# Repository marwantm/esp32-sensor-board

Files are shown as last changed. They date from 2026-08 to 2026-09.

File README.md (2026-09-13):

# ESP32 Sensor Board

A 4-layer ESP32-C3 IoT sensor board with onboard LiPo charging, SD storage, and a multi-sensor front end, designed in KiCad by following Tech Explorations' full board-development pipeline tutorial — my most advanced build yet, covering the complete flow from schematic to manufacturing and assembly.

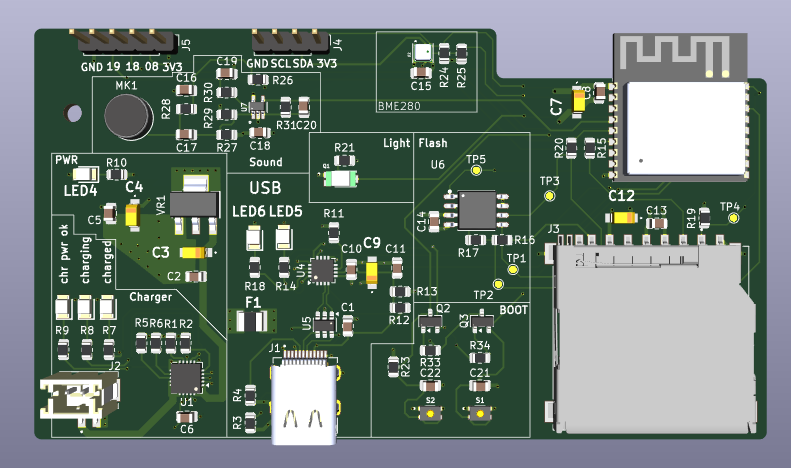
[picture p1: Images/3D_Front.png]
PCB 3D Front


## Overview

This board is built around the **ESP32-C3-WROOM-02**, a RISC-V Wi-Fi/BLE module, paired with a small sensor suite (environmental, audio, and light), onboard SPI flash, microSD storage, and a full LiPo battery charging path — a compact, self-contained IoT sensor node platform.

| | |
|---|---|
| **MCU** | ESP32-C3-WROOM-02 (RISC-V, Wi-Fi + BLE) |
| **Sensors** | BME280 (temperature/humidity/pressure), electret mic + MAX4466 amplifier, TEMT6000 ambient light sensor |
| **Storage** | W25Q32JVSSIQ SPI flash (32 Mbit) + microSD card slot |
| **Connectivity** | USB-C (via CP2102N USB-UART bridge), I2C header for OLED display, GPIO breakout |
| **Power** | USB-C (5V) or LiPo battery (JST connector), MCP73871 Li-ion/LiPo charge management, LM1117MPX-3.3 LDO |
| **Programming** | Auto-program circuit (DTR/RTS → EN/IO0 via BC817 transistors) — no manual boot/reset sequence needed |
| **PCB** | 4-layer |
| **Design Tool** | KiCad 9 |

## What I Learned

This project pushed further than my previous boards, moving from single-sheet schematics and simple 2-layer boards into a full multilayer design with manufacturing and assembly considerations built in from the start:

**Schematic Design**
- Multi-sheet hierarchical schematic structure, splitting the design into logical sub-sheets (USB/flash, sensors, user interface, power)
- Creating a custom KiCad component library for parts not available in the standard libraries, registered globally for reuse in future projects
- Designing a complete LiPo charging path around the MCP73871, including charge-status indication (charging/charged LEDs) and battery sense/thermistor handling

**PCB Layout**
- Working with a 4-layer stack-up and signal tuning across layers
- Zone fills across both available and non-available power planes, and understanding how that affects plane continuity and return paths
- Component placement and routing for mixed digital, analog (microphone/amp), and RF (Wi-Fi/BLE) sections on the same board

**Manufacturing & Assembly**
- Design for Manufacturability (DFM) checks using HQDFM (NextPCB)
- Generating centroid (pick-and-place) files for PCB assembly
- Thinking through the board as something meant to be assembled by a fab, not just etched and hand-soldered

## Gallery

| Schematic (Power & USB) | Schematic (ESP32, USB, Flash) |
|---|---|
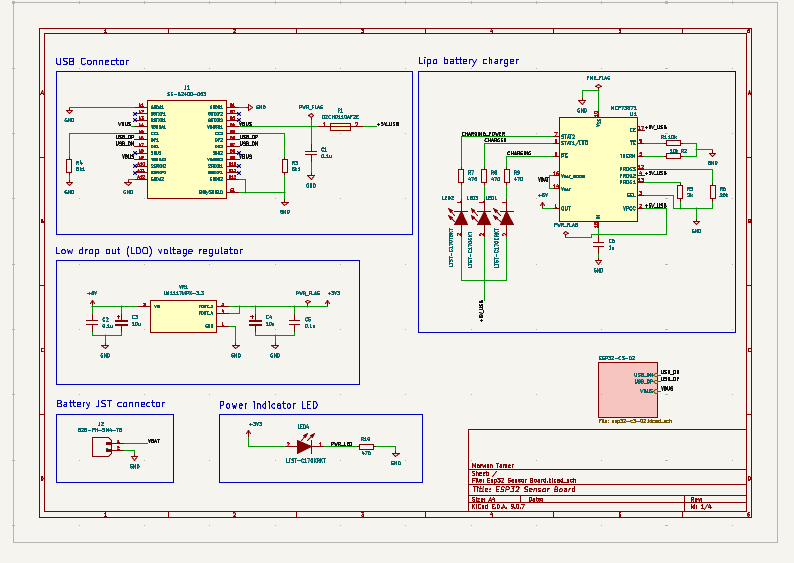
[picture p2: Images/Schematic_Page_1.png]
Schematic Page 1
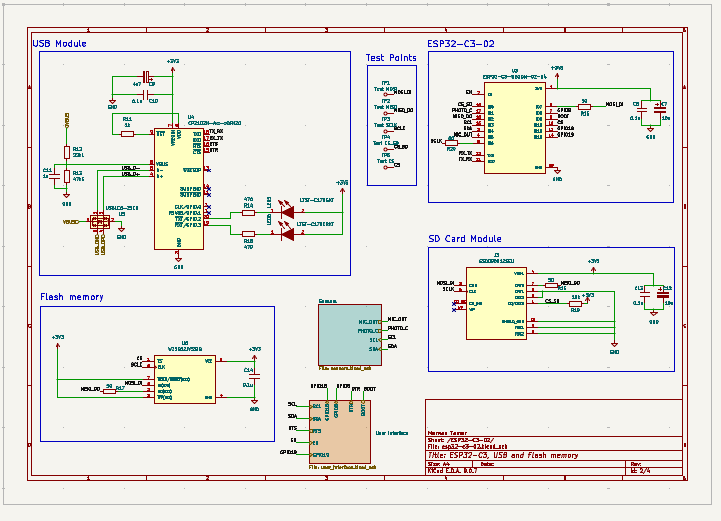
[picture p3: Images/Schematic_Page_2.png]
Schematic Page 2
|  |  |

| Schematic (Sensors) | Schematic (User Interface) |
|---|---|
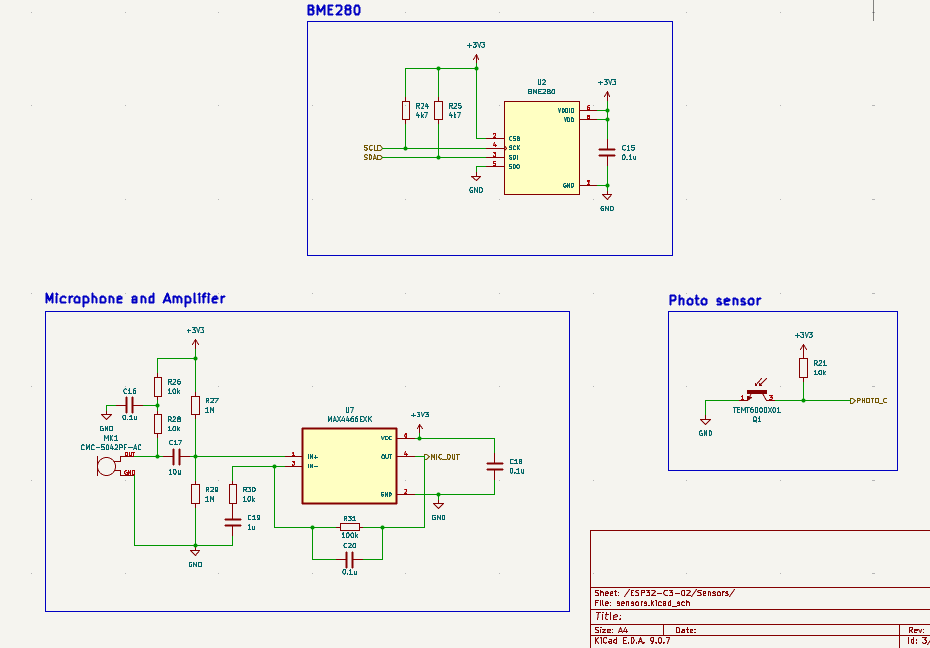
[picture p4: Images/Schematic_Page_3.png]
Schematic Page 3
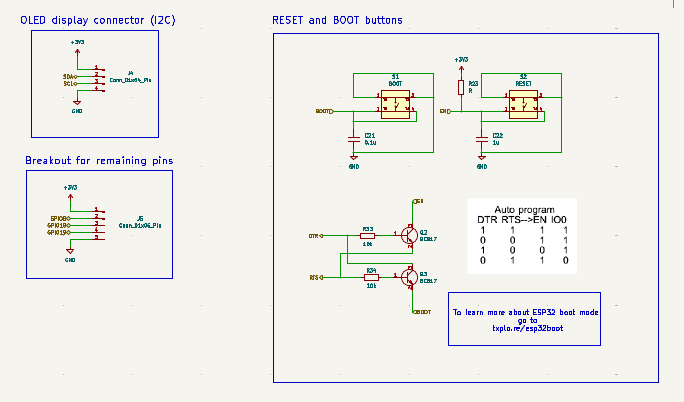
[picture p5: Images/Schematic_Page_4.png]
Schematic Page 4
|  |  |

| PCB Top | PCB Bottom |
|---|---|
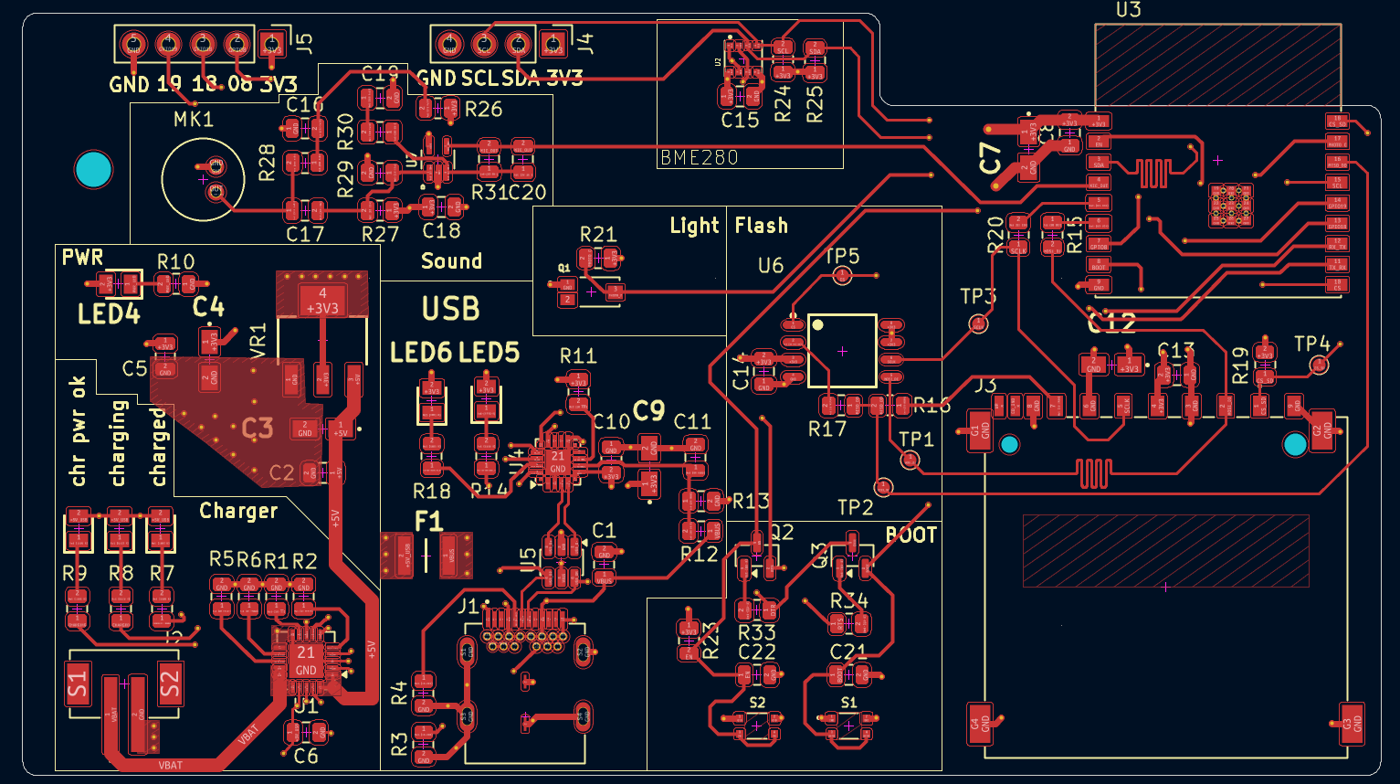
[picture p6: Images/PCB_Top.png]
PCB Top
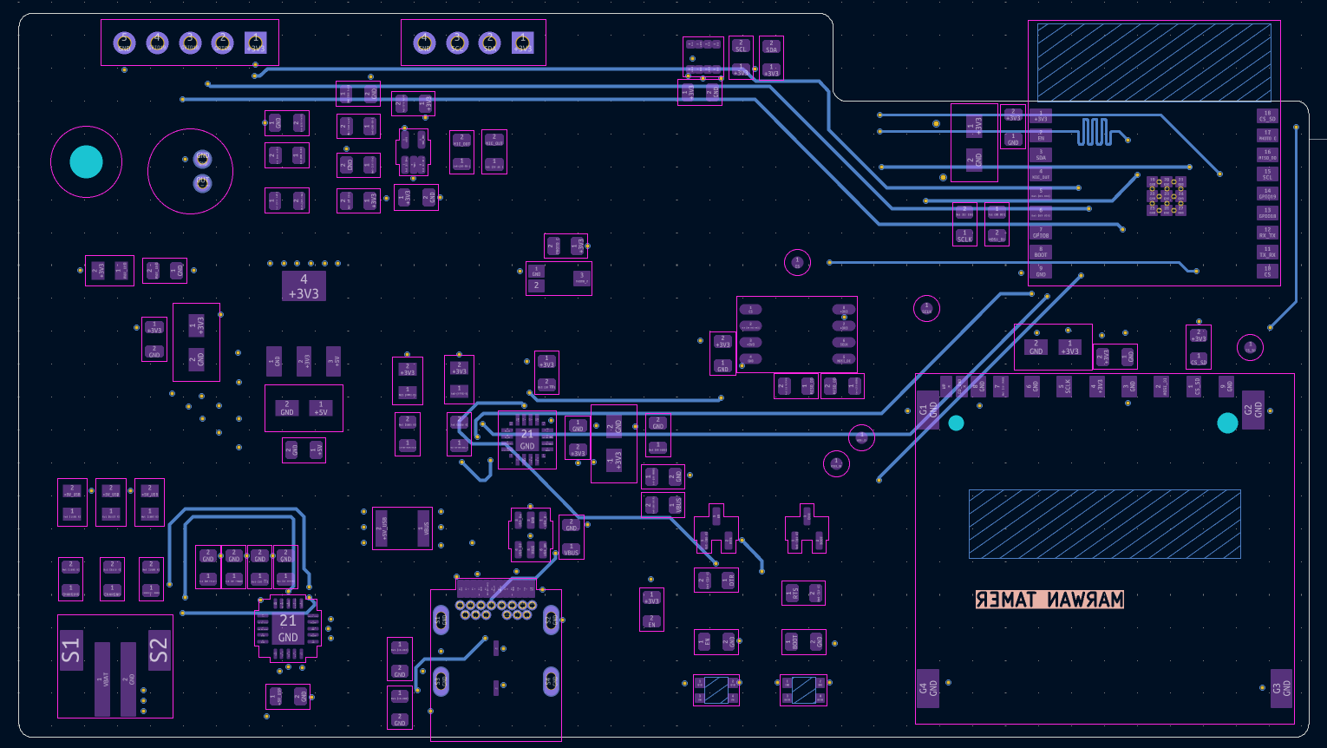
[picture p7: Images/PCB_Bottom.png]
PCB Bottom
|  |  |

| 3D Front | 3D Back |
|---|---|
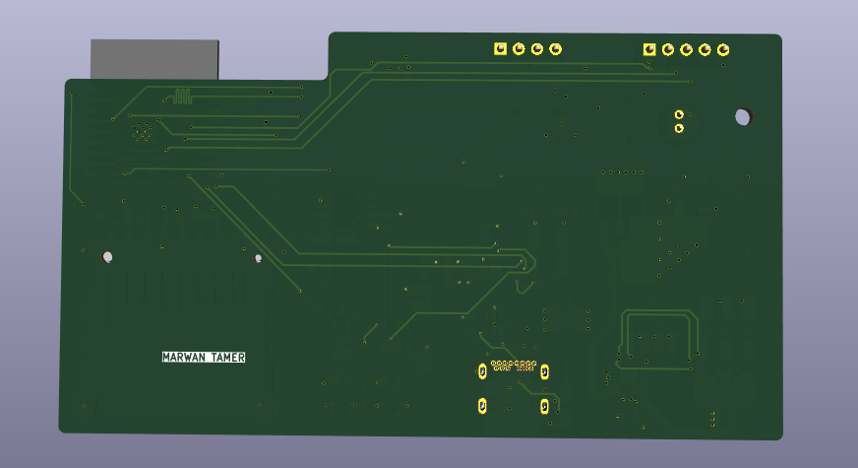
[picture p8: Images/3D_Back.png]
3D Back
| 3D Front |  |

## Repository Structure

```
ESP32-Sensor-Board/
├── README.md
├── Hardware/                        # Manufacturing-ready outputs
│   ├── ESP32 Sensor Board_Schematic.pdf
│   ├── ESP32 Sensor Board_PCB.pdf
│   ├── BOM.csv
│   └── Gerbers.zip
├── Images/                          # Renders and layer screenshots
│   ├── 3D_Back.png
│   ├── 3D_Front.png
│   ├── PCB_Bottom.png
│   ├── PCB_Top.png
│   ├── Schematic_Page_1.png
│   ├── Schematic_Page_2.png
│   ├── Schematic_Page_3.png
│   └── Schematic_Page_4.png
└── Source Files/                    # Full KiCad project (editable source)
    ├── Additional Components/       # Custom library (parts, footprints)
    ├── Esp32 Sensor Board.kicad_pcb
    ├── Esp32 Sensor Board.kicad_prl
    ├── Esp32 Sensor Board.kicad_pro
    ├── Esp32 Sensor Board.kicad_sch
    ├── esp32-c3-02.kicad_sch
    ├── sensors.kicad_sch
    ├── user_interface.kicad_sch
    └── fp-lib-table
```

## Credit

Built by following [Tech Explorations](https://www.linkedin.com/company/techexplorations/)'s ESP32 sensor board tutorial, which covers the complete pipeline from board specification through ordering and assembly. This project is a learning exercise, not an original design — full credit for the schematic architecture and design decisions goes to Tech Explorations' tutorial series.

## Author

**Marwan Tamer**
Electrical Power Engineering student, building toward Embedded Systems Engineering
[LinkedIn](https://www.linkedin.com/in/-marwan-tamer)

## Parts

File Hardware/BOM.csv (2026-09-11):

Reference | Qty | Value | DNP | Exclude from BOM | Exclude from Board | Footprint | Datasheet
C1,C2,C5,C8,C10,C13,C14,C15,C16,C18,C20,C21 | 12 | 0.1u |  |  |  | Capacitor_SMD:C_0805_2012Metric | ~
C3,C4,C7,C12 | 4 | 10u |  |  |  | My_Library:T491A | ~
C6,C11,C19,C22 | 4 | 1u |  |  |  | Capacitor_SMD:C_0805_2012Metric | ~
C9 | 1 | 4u7 |  |  |  | My_Library:T491A | ~
C17 | 1 | 10u |  |  |  | Capacitor_SMD:C_0805_2012Metric | ~
F1 | 1 | 0ZCH0110AF2E |  |  |  | My_Library:FUSC3226X100N | https://www.belfuse.com/resources/datasheets/circuitprotection/ds-cp-0zch-series.pdf
J1 | 1 | SS-52400-003 |  |  |  | My_Library:BELFUSE_SS-52400-003
J2 | 1 | B2B-PH-SM4-TB |  |  |  | My_Library:JST_B2B-PH-SM4-TB
J3 | 1 | GSD090012SEU |  |  |  | My_Library:AMPHENOL_GSD090012SEU
J4 | 1 | Conn_01x04_Pin |  |  |  | Connector_PinHeader_2.54mm:PinHeader_1x04_P2.54mm_Vertical | ~
J5 | 1 | Conn_01x05_Pin |  |  |  | Connector_PinHeader_2.54mm:PinHeader_1x05_P2.54mm_Vertical | ~
LED1,LED4,LED6 | 3 | LTST-C170KRKT |  |  |  | My_Library:LEDC2012X120N | https://componentsearchengine.com/Datasheets/1/LTST-C170KRKT.pdf
LED2 | 1 | LTST-C170TBKT |  |  |  | My_Library:LEDC2012X120N | https://componentsearchengine.com/Datasheets/1/LTST-C170TBKT.pdf
LED3,LED5 | 2 | LTST-C170GKT |  |  |  | My_Library:LEDC2012X120N | https://mm.digikey.com/Volume0/opasdata/d220001/medias/docus/895/LTST-C170GKT.pdf
MK1 | 1 | CMC-5042PF-AC |  |  |  | My_Library:CUI_CMC-5042PF-AC
Q1 | 1 | TEMT6000X01 |  |  |  | My_Library:TRANS_TEMT6000X01
Q2,Q3 | 2 | BC817 |  |  |  | Package_TO_SOT_SMD:SOT-23 | https://www.onsemi.com/pub/Collateral/BC818-D.pdf
R1,R2,R19,R21,R26,R28,R30,R33,R34 | 9 | 10k |  |  |  | Resistor_SMD:R_0805_2012Metric | ~
R3,R4 | 2 | 5k1 |  |  |  | Resistor_SMD:R_0805_2012Metric | ~
R5 | 1 | 2k |  |  |  | Resistor_SMD:R_0805_2012Metric | ~
R6 | 1 | 20k |  |  |  | Resistor_SMD:R_0805_2012Metric | ~
R7,R8,R9,R10,R14,R18 | 6 | 470 |  |  |  | Resistor_SMD:R_0805_2012Metric | ~
R11 | 1 | 1k |  |  |  | Resistor_SMD:R_0805_2012Metric | ~
R12 | 1 | 22k1 |  |  |  | Resistor_SMD:R_0805_2012Metric | ~
R13 | 1 | 47k5 |  |  |  | Resistor_SMD:R_0805_2012Metric | ~
R15,R16,R17,R20 | 4 | 50 |  |  |  | Resistor_SMD:R_0805_2012Metric | ~
R23 | 1 | R |  |  |  | Resistor_SMD:R_0805_2012Metric | ~
R24,R25 | 2 | 4k7 |  |  |  | Resistor_SMD:R_0805_2012Metric | ~
R27,R29 | 2 | 1M |  |  |  | Resistor_SMD:R_0805_2012Metric | ~
R31 | 1 | 100k |  |  |  | Resistor_SMD:R_0805_2012Metric | ~
S1 | 1 | BOOT |  |  |  | My_Library:SW_USLPT2819DT2TR
S2 | 1 | RESET |  |  |  | My_Library:SW_USLPT2819DT2TR
TP1 | 1 | Test MOSI |  |  |  | TestPoint:TestPoint_Pad_D1.0mm | ~
TP2 | 1 | Test MISO |  |  |  | TestPoint:TestPoint_Pad_D1.0mm | ~
TP3 | 1 | Test SCLK |  |  |  | TestPoint:TestPoint_Pad_D1.0mm | ~
TP4 | 1 | Test CS_SD |  |  |  | TestPoint:TestPoint_Pad_D1.0mm | ~
TP5 | 1 | Test CS |  |  |  | TestPoint:TestPoint_Pad_D1.0mm | ~
U1 | 1 | MCP73871 |  |  |  | Package_DFN_QFN:QFN-20-1EP_4x4mm_P0.5mm_EP2.5x2.5mm | http://www.mouser.com/ds/2/268/22090a-52174.pdf
U2 | 1 | BME280 |  |  |  | My_Library:PSON65P250X250X100-8N
U3 | 1 | ESP32-C3-WROOM-02-H4 |  |  |  | My_Library:MODULE_ESP32-C3-WROOM-02-H4
U4 | 1 | CP2102N-Axx-xQFN20 |  |  |  | Package_DFN_QFN:SiliconLabs_QFN-20-1EP_3x3mm_P0.5mm_EP1.8x1.8mm | https://www.silabs.com/documents/public/data-sheets/cp2102n-datasheet.pdf
U5 | 1 | USBLC6-2SC6 |  |  |  | Package_TO_SOT_SMD:SOT-23-6 | https://www.st.com/resource/en/datasheet/usblc6-2.pdf
U6 | 1 | W25Q32JVSSIQ |  |  |  | My_Library:SOIC127P790X216-8N
U7 | 1 | MAX4466EXK |  |  |  | My_Library:SOT65P210X110-5N
VR1 | 1 | LM1117MPX-3.3 |  |  |  | My_Library:VREG_LM1117MPX-3.3

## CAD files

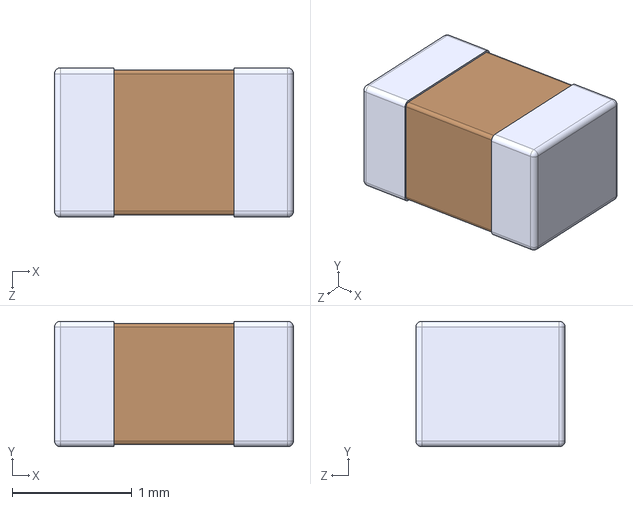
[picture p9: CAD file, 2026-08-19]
Source Files/Additional Components/3D models/FBMJ2125HM330-T.step
2.00 x 1.05 x 1.25 mm

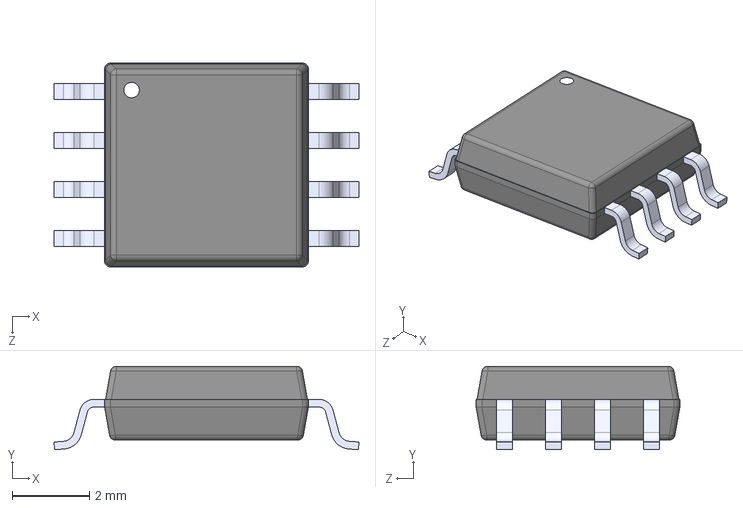
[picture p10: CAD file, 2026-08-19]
Source Files/Additional Components/3D models/W25Q32JVSSIQ.step
7.90 x 2.16 x 5.28 mm

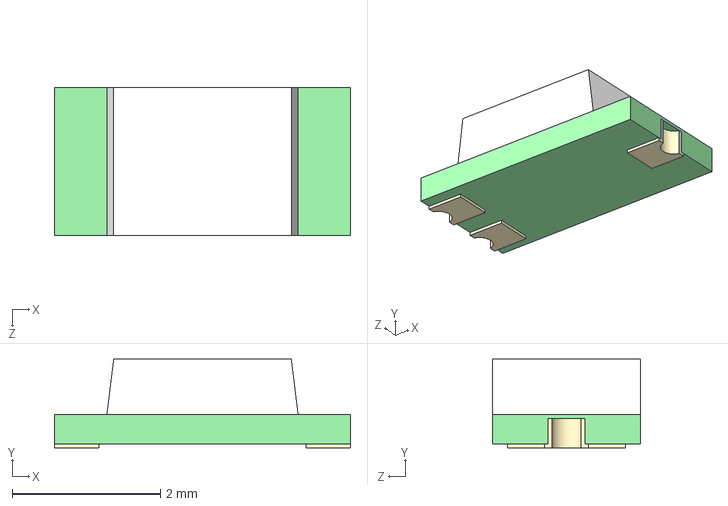
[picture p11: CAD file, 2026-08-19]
Source Files/Additional Components/3D models/TEMT6000X01.step
4.00 x 1.20 x 2.00 mm

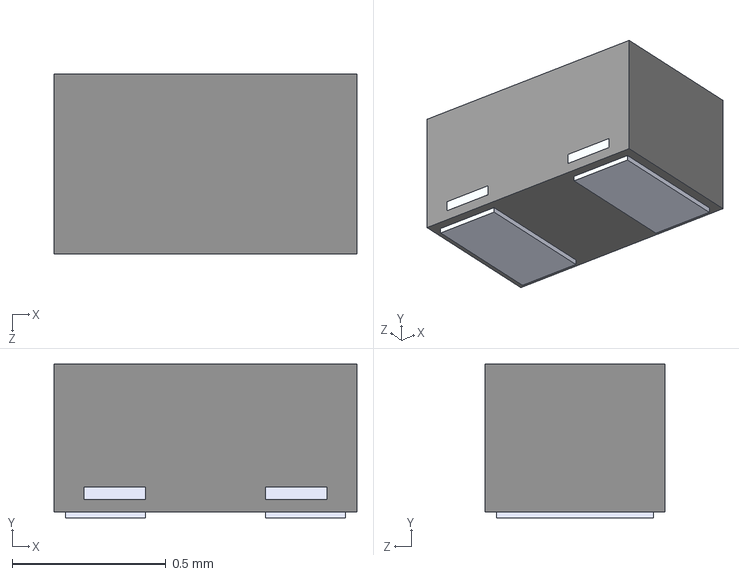
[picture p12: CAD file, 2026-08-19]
Source Files/Additional Components/3D models/PESD5V0S1UL_315.step
0.985 x 0.5 x 0.585 mm

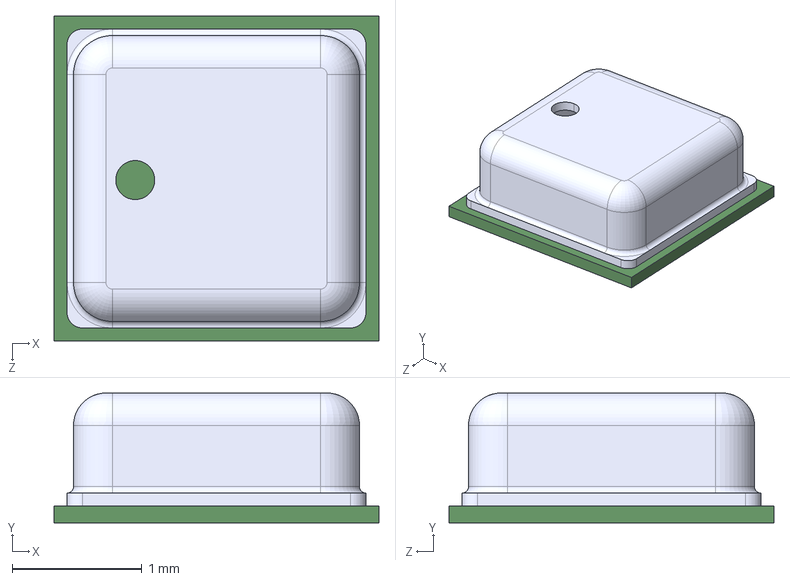
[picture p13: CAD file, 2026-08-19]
Source Files/Additional Components/3D models/BME280.step
2.50 x 1.00 x 2.50 mm

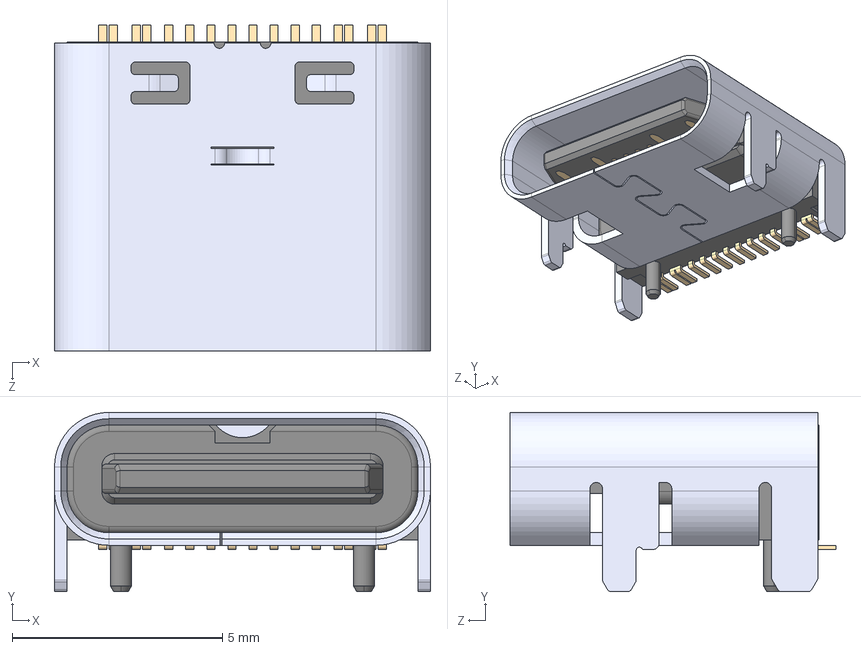
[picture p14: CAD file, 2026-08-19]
Source Files/Additional Components/3D models/CSP-USC16-TR.step
8.94 x 4.26 x 7.75 mm

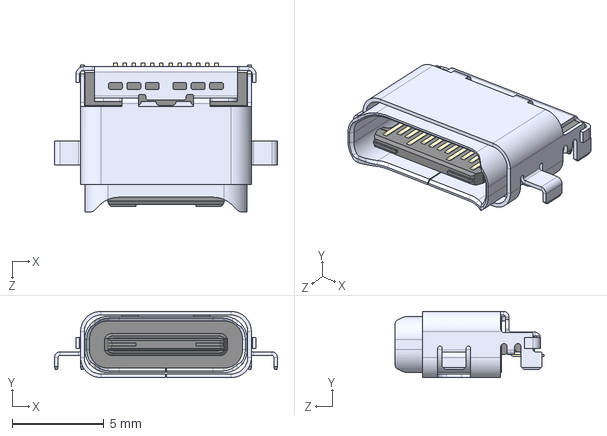
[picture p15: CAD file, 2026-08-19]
Source Files/Additional Components/3D models/1-2295018-2.step
12.1 x 3.60 x 8.10 mm

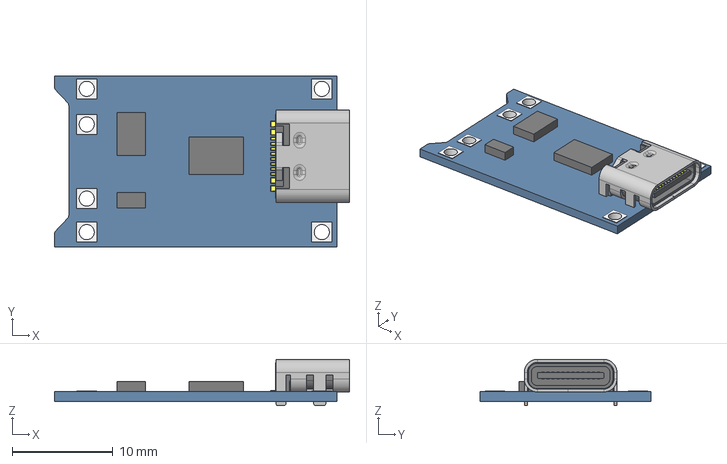
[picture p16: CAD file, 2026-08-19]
Source Files/Additional Components/3D models/TP4056.step
29.3 x 17.0 x 4.60 mm

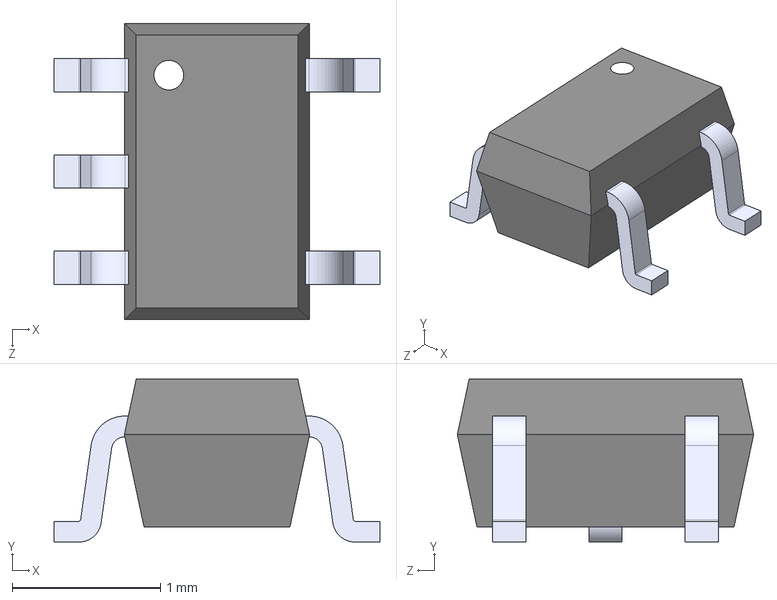
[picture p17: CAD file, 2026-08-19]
Source Files/Additional Components/3D models/MAX4466EXK.step
2.20 x 1.10 x 2.00 mm

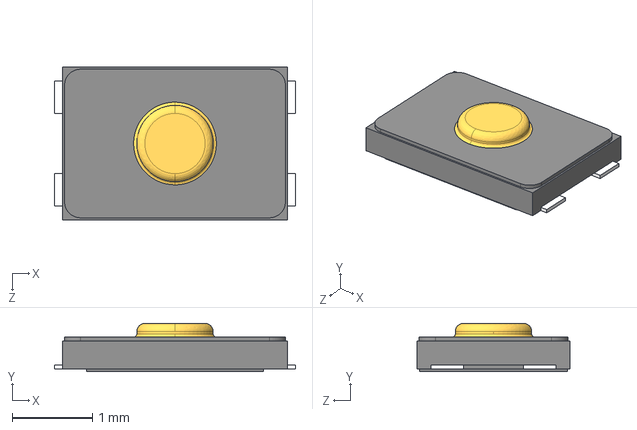
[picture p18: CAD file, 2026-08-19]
Source Files/Additional Components/3D models/USLPT2819DT2TR.step
3.00 x 0.6 x 1.90 mm

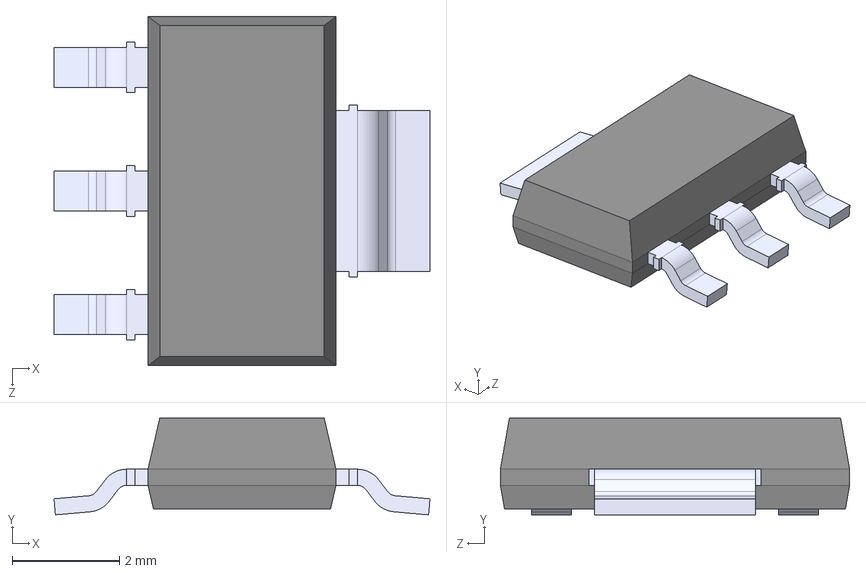
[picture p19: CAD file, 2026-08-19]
Source Files/Additional Components/3D models/LM1117MPX-3.3.step
7.00 x 1.80 x 6.50 mm

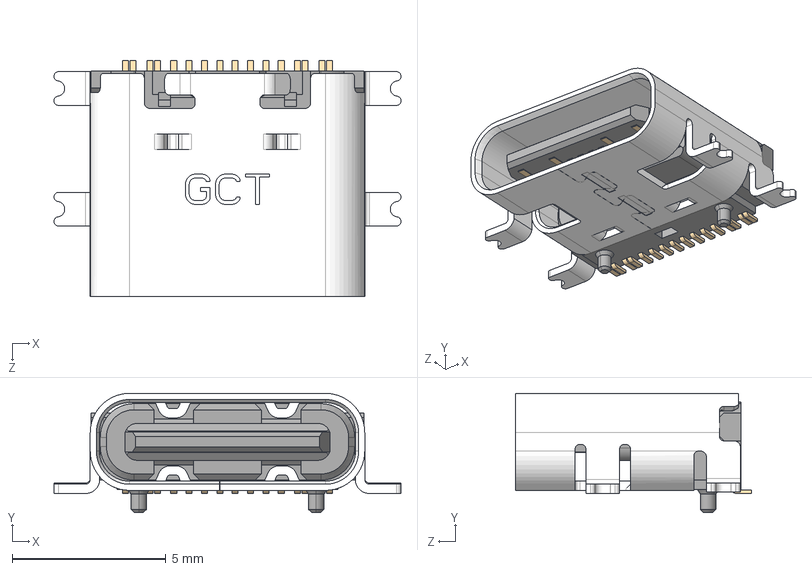
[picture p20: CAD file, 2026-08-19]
Source Files/Additional Components/3D models/USB4110GFA.step
11.3 x 3.89 x 7.70 mm

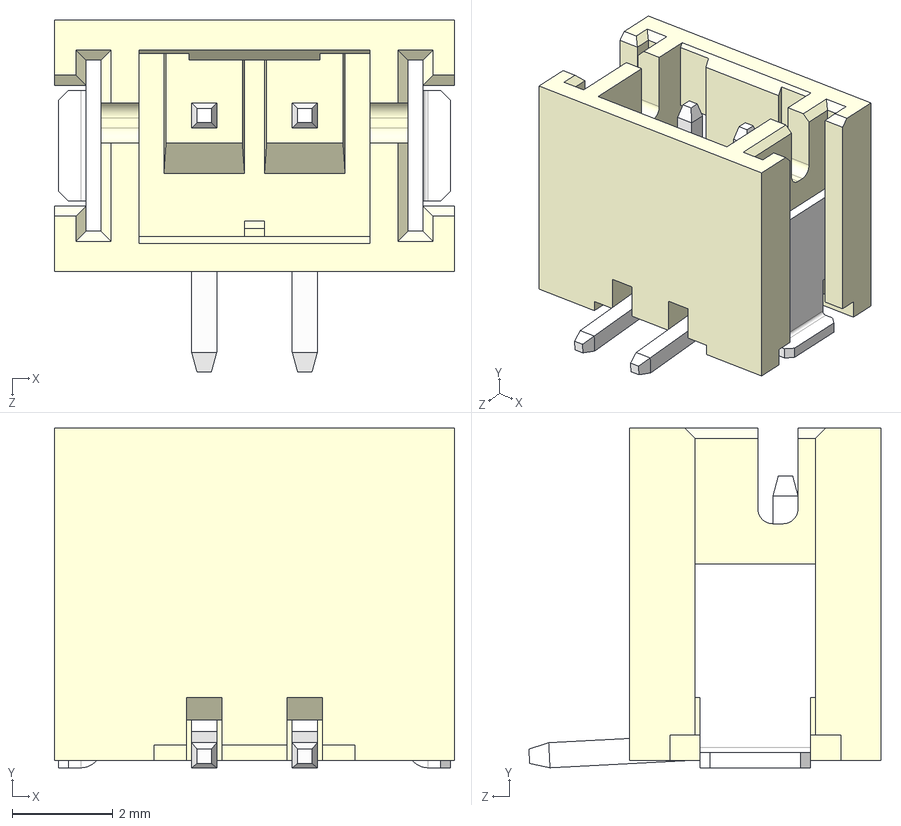
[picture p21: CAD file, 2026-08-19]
Source Files/Additional Components/3D models/B2B-PH-SM4-TB.step
7.95 x 6.75 x 7.00 mm

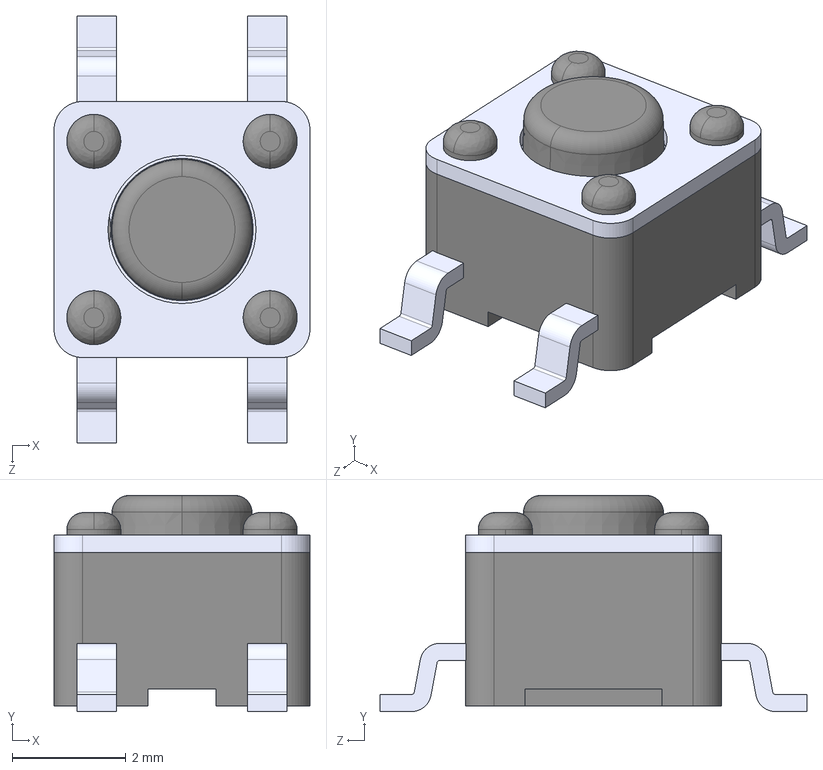
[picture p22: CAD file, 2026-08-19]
Source Files/Additional Components/3D models/TL3305AF260QG.step
4.50 x 3.80 x 7.50 mm

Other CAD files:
Source Files/Additional Components/3D models/LM1117MPX-3.3_NOPB.step
Source Files/Additional Components/3D models/SS-52400-002.step
Source Files/Additional Components/3D models/ESP32-C3-WROOM-02-H4.step
Source Files/Additional Components/3D models/B4B-XH-AM__LF__SN_.step
Source Files/Additional Components/3D models/GSD090012SEU.step
Source Files/Additional Components/3D models/MCP73871-2CAI_ML.step
Source Files/Additional Components/3D models/SMD-BUTTON_4P-5.2X5.2X1.5MM-SKQGADE010_.step

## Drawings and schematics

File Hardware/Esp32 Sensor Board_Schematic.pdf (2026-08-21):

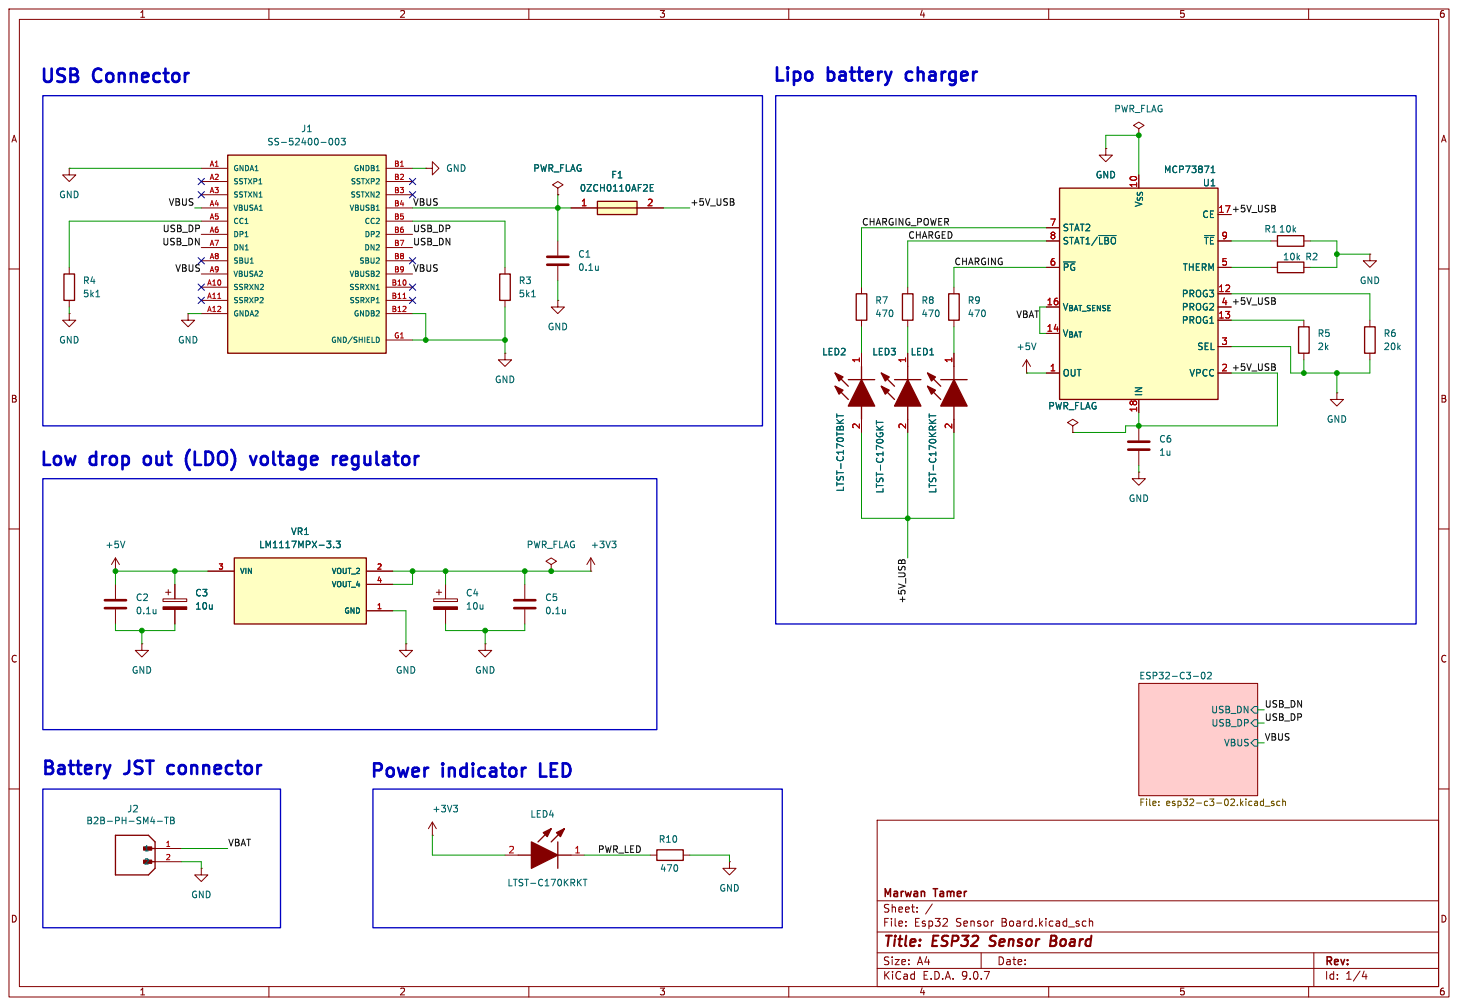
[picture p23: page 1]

Low drop out (LDO) voltage regulator

Id: 1/4 Title: ESP32 Sensor Board

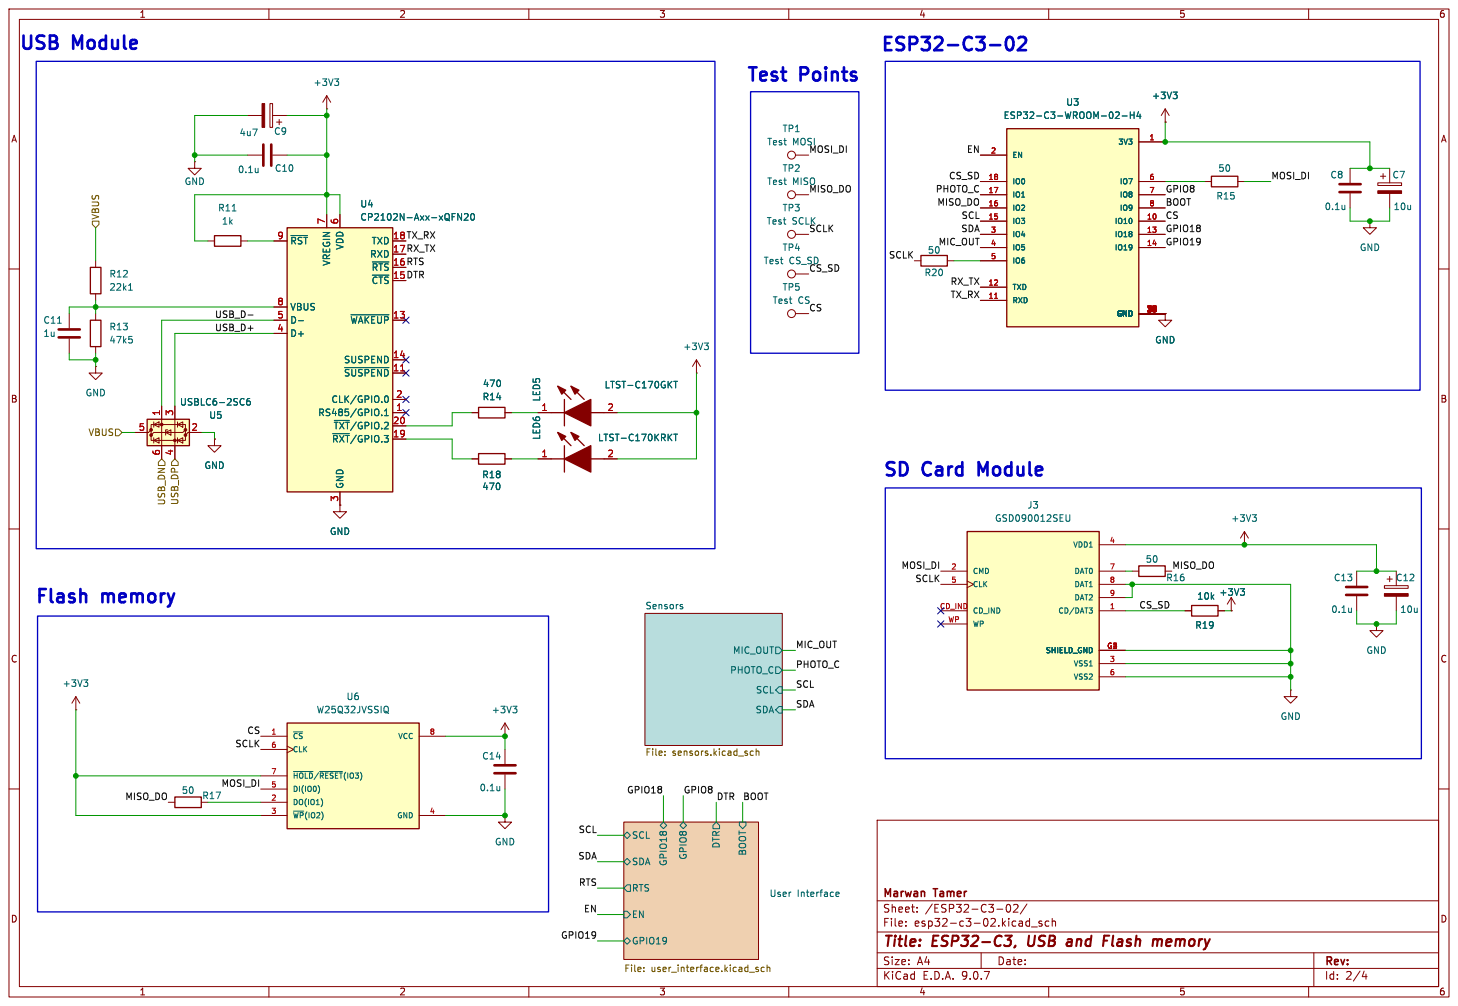
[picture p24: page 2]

3 TXD 18 RXD 17 ~{RTS} 16 ~{CTS} 15 ~{WAKEUP} 13 SUSPEND 14 ~{SUSPEND}11 CLK/GPIO.0 2 RS485/GPIO.1 1 ~{TXT}/GPIO.220 ~{RXT}/GPIO.319 U4 CP2102N-Axx-xQFN20 R14

3 TXD 18 RXD 17 ~{RTS} 16 ~{CTS} 15 ~{WAKEUP} 13 SUSPEND 14 ~{SUSPEND}11 CLK/GPIO.0 2 RS485/GPIO.1 1 ~{TXT}/GPIO.220 ~{RXT}/GPIO.319 GND
USB_D- USB_D+ MOSI_DI CS

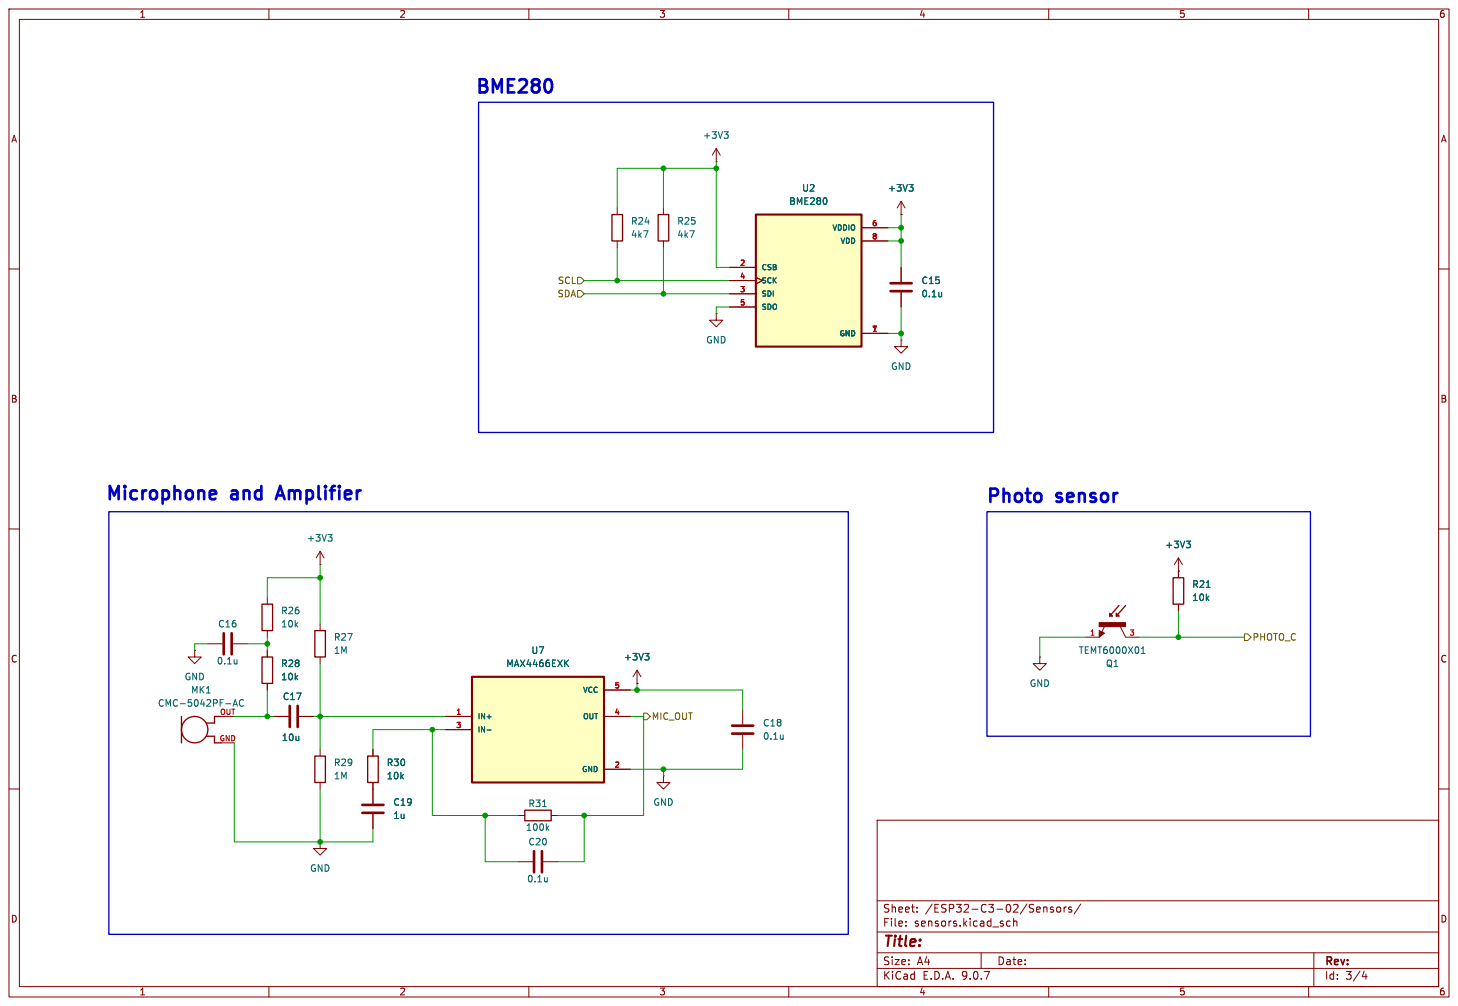
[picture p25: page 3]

SCL Microphone and Amplifier

0.1u OUT GND MK1 CMC-5042PF-AC

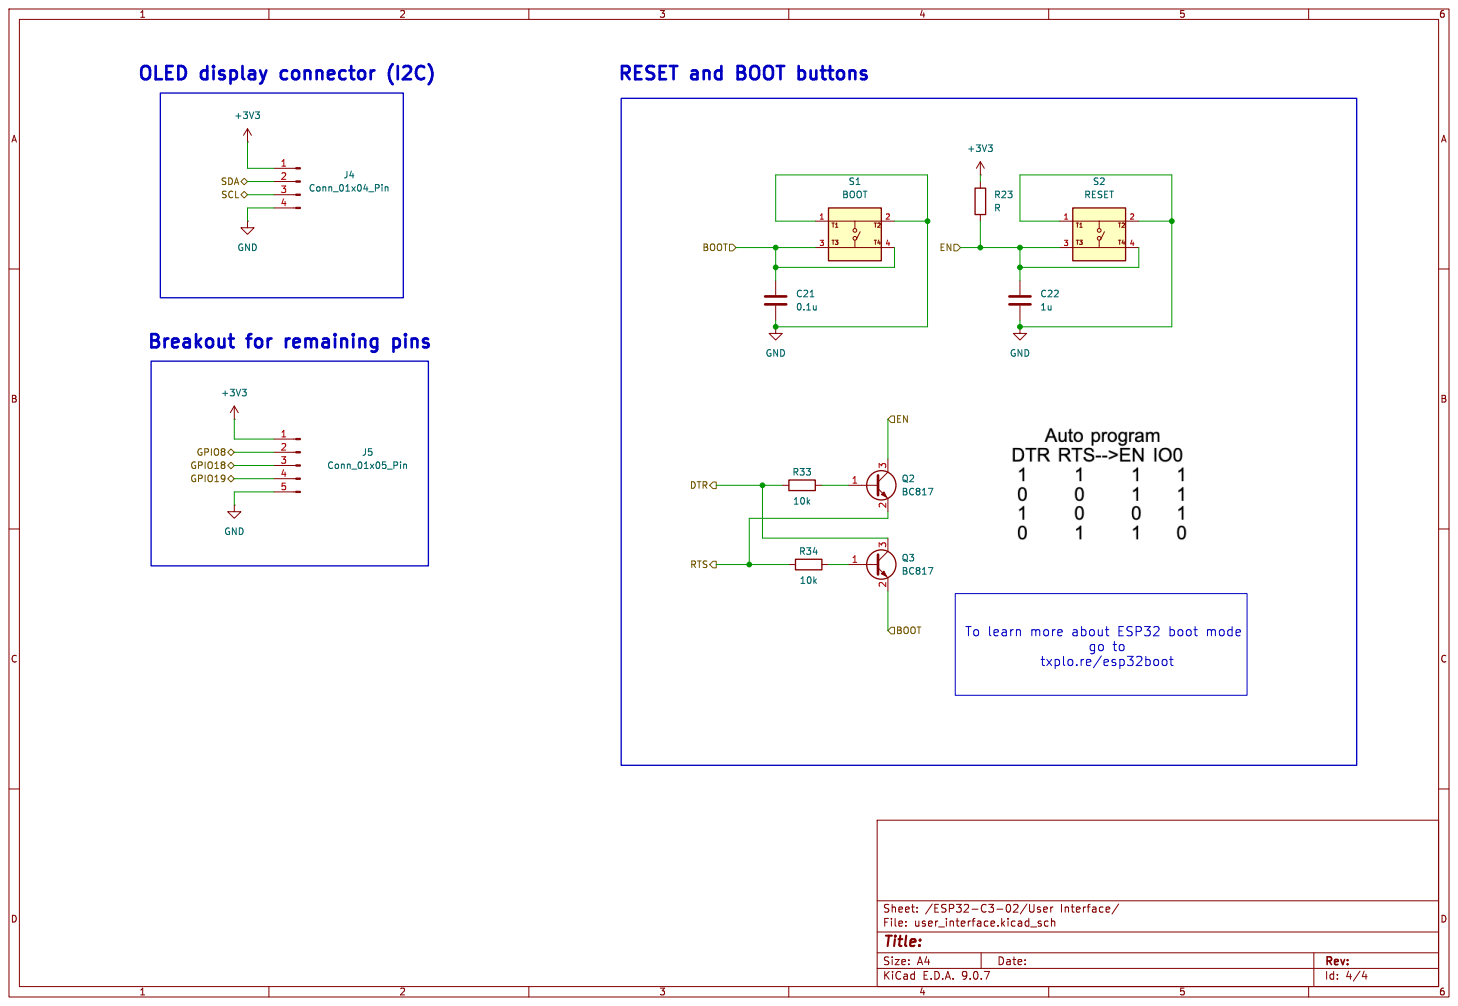
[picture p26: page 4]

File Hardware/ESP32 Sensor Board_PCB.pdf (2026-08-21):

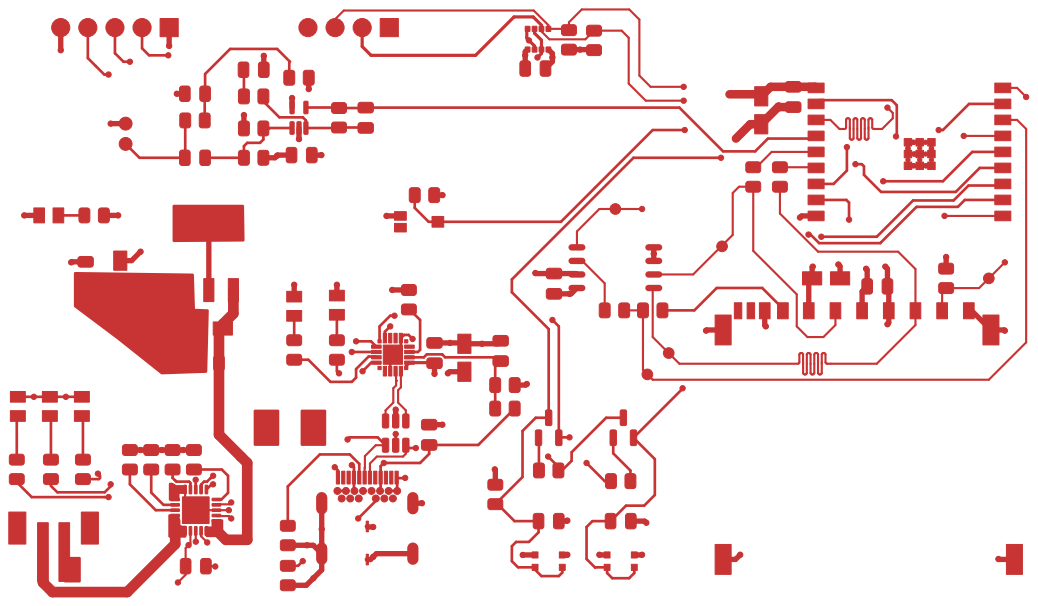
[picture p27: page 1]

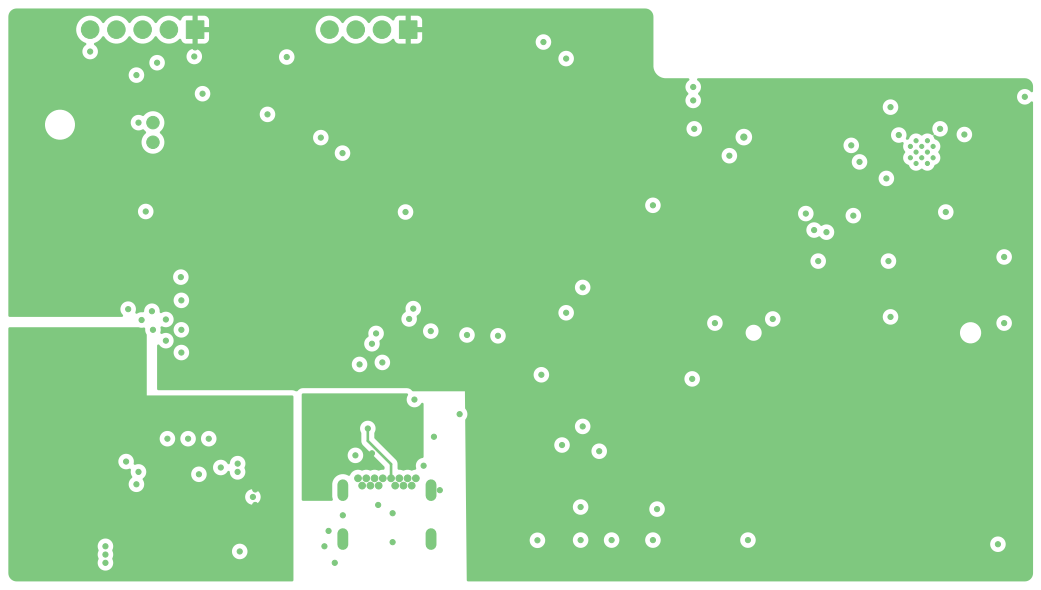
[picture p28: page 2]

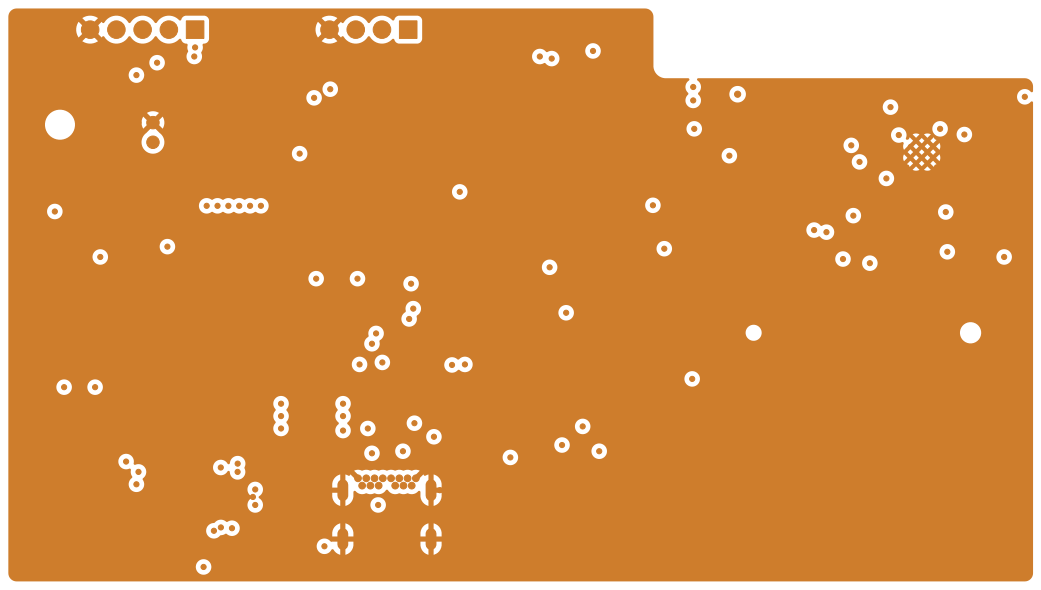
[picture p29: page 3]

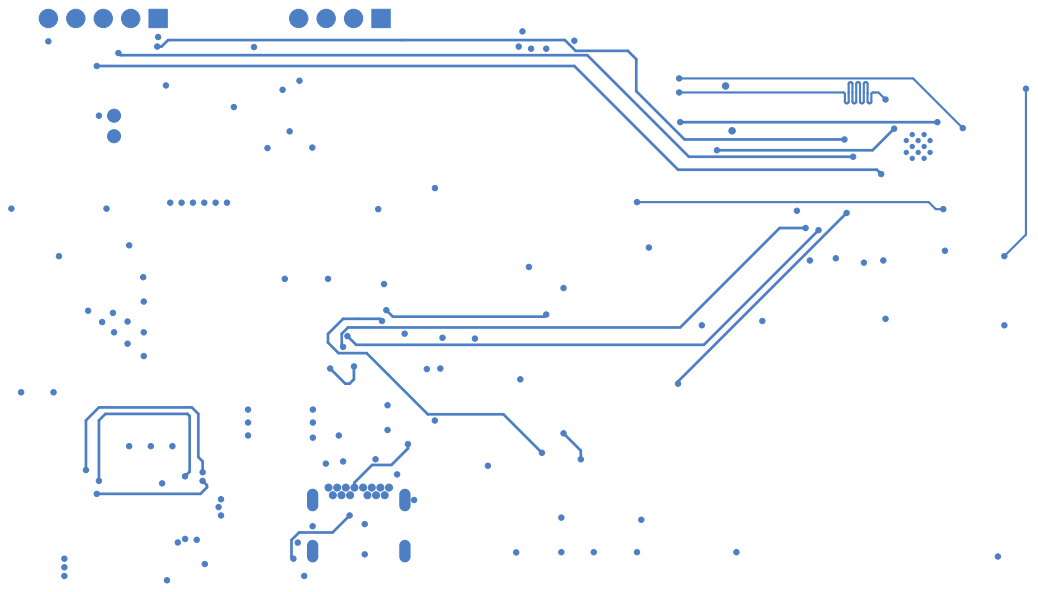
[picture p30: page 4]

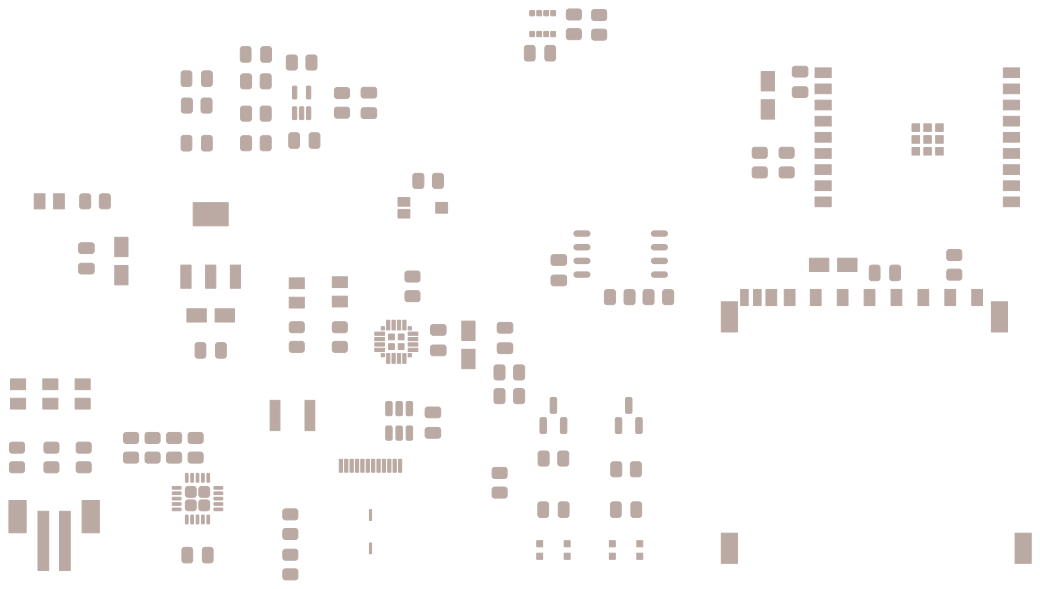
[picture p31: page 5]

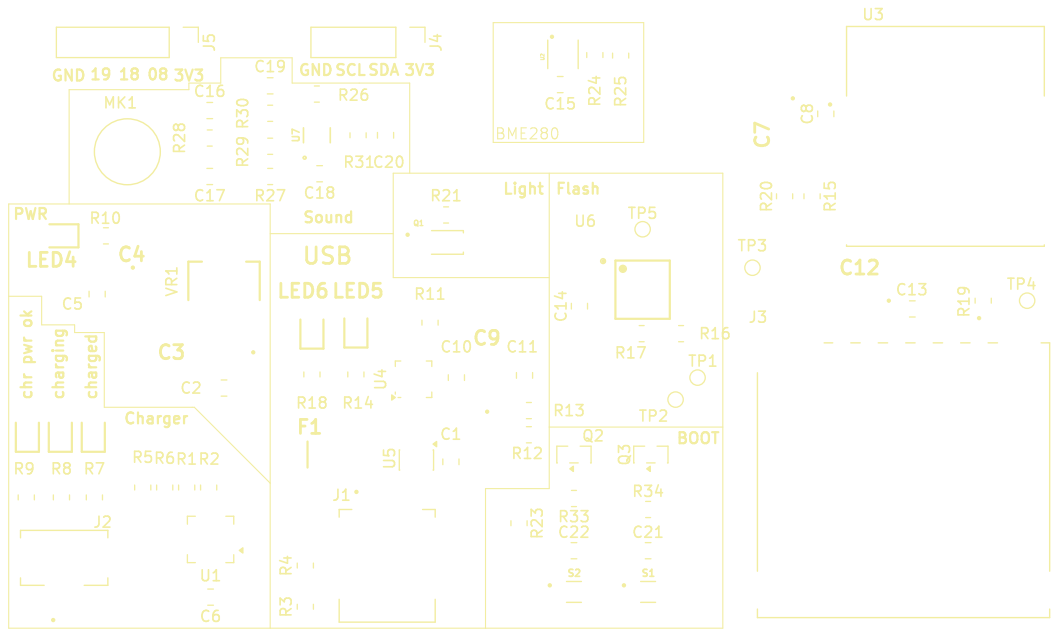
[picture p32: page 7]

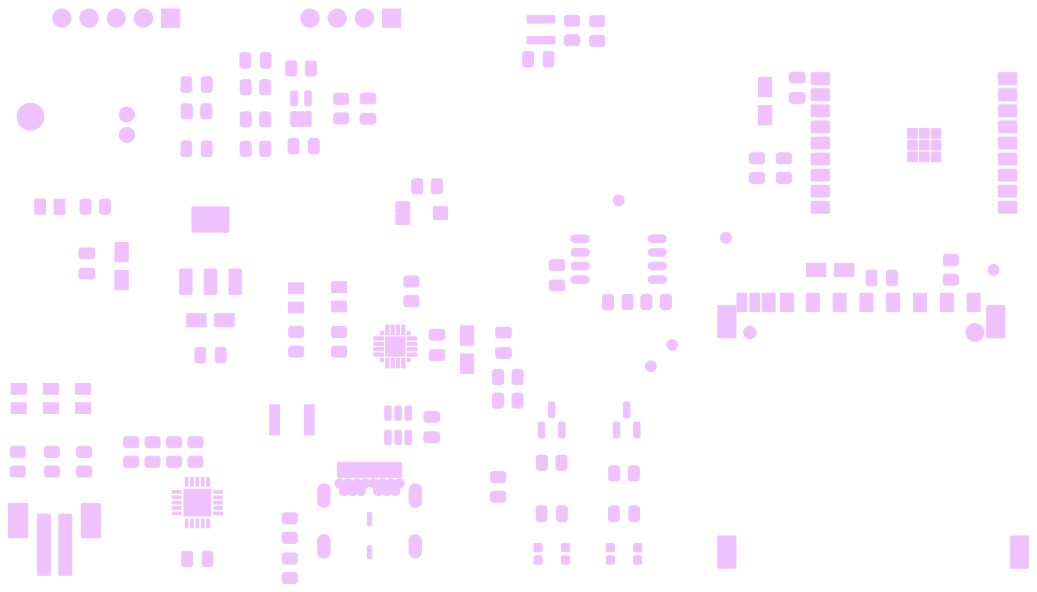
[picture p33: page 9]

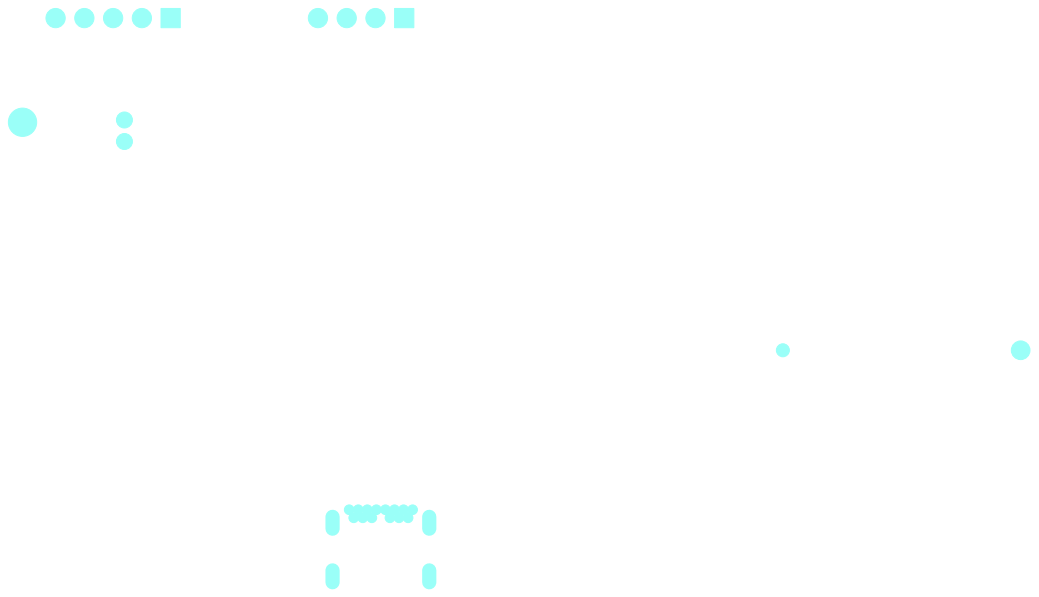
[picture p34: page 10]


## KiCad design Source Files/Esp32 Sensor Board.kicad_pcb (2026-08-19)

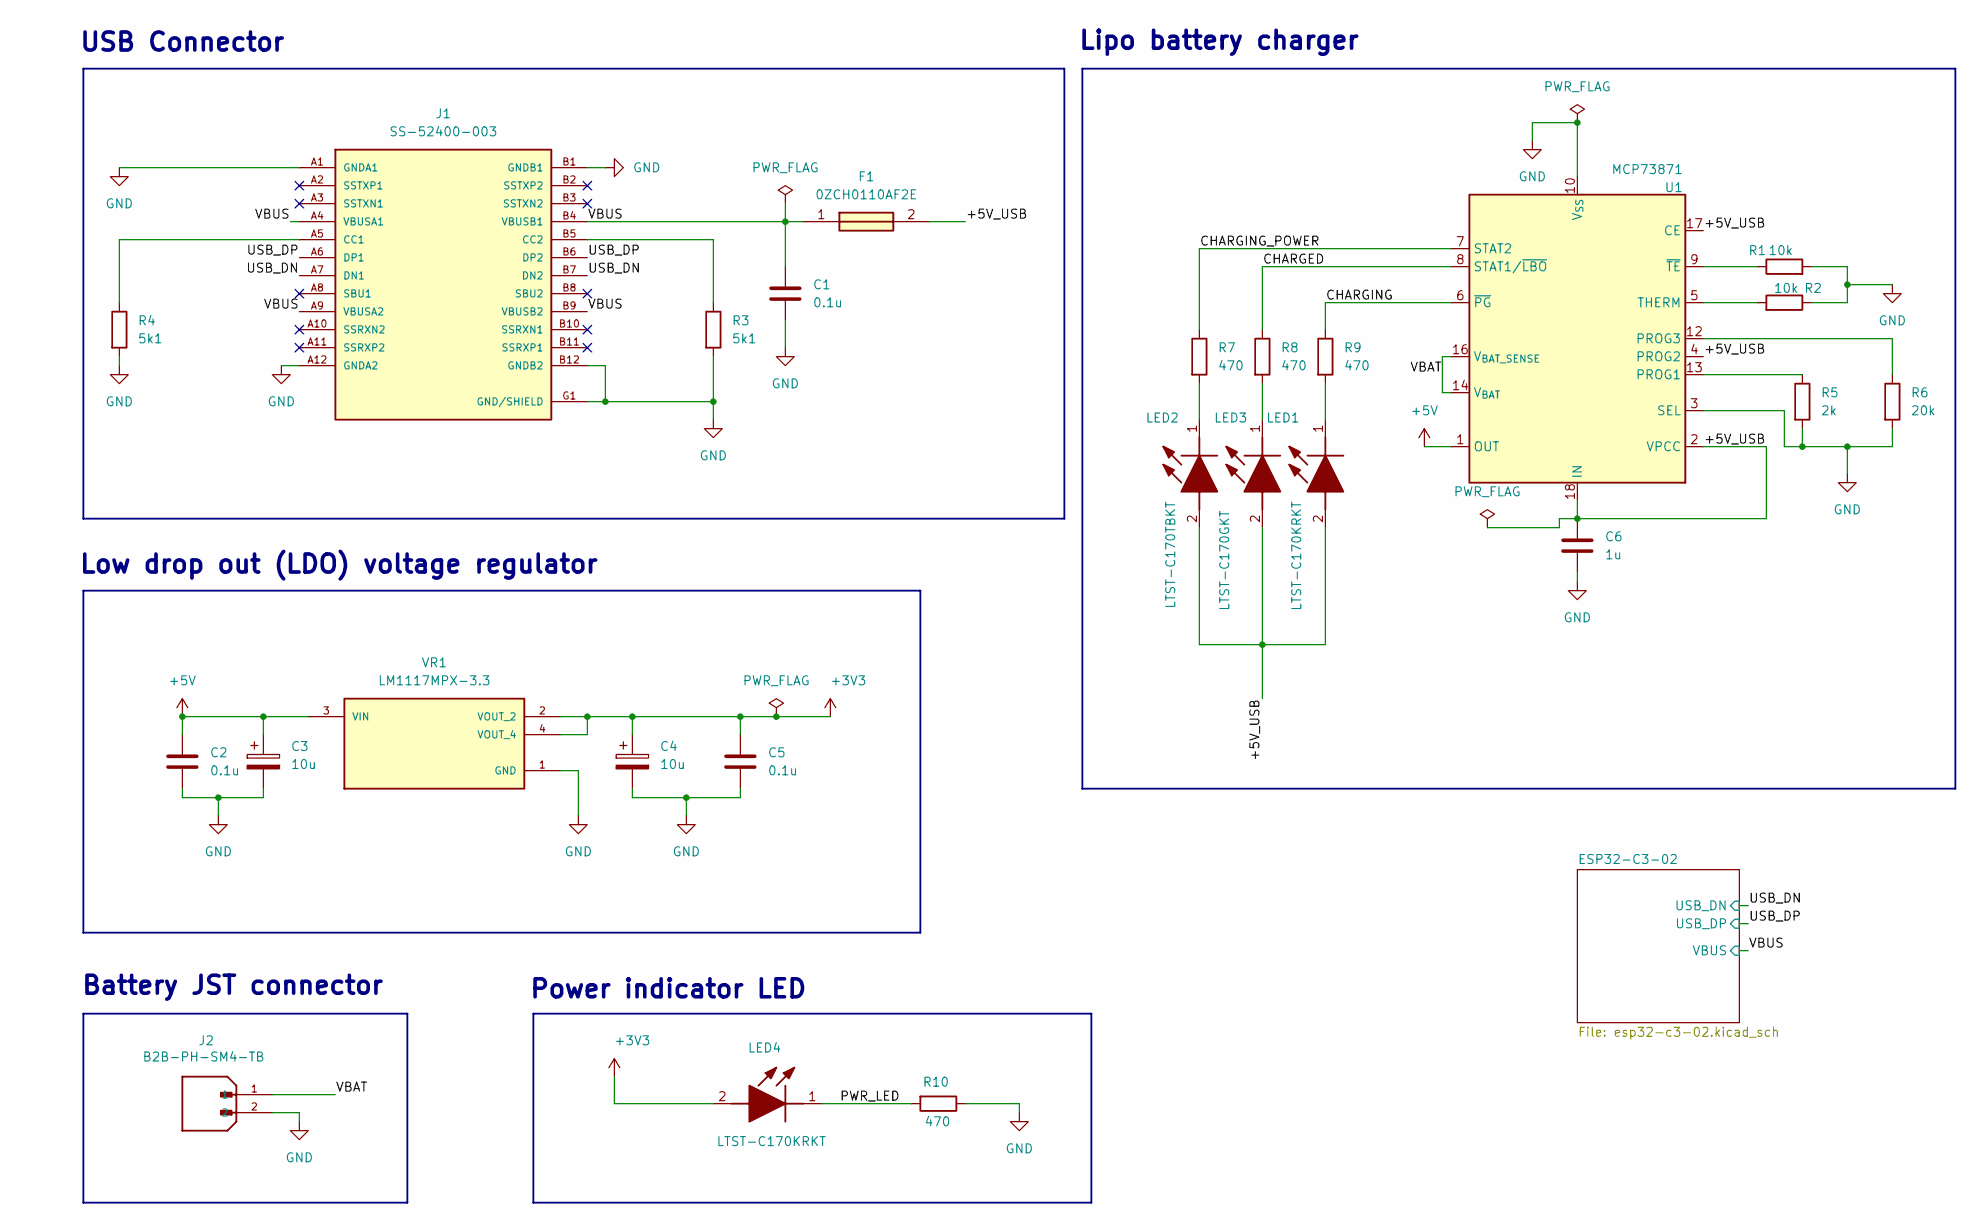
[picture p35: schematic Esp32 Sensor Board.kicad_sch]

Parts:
C1, C2, C5: 0.1u; C_0805_2012Metric
C3, C4: 10u; T491A
C6: 1u; C_0805_2012Metric
F1: 0ZCH0110AF2E; FUSC3226X100N; Manufacturer_Part_Number 0ZCH0110AF2E
J1: SS-52400-003; BELFUSE_SS-52400-003; PARTREV A0
J2: B2B-PH-SM4-TB; JST_B2B-PH-SM4-TB; PARTREV N/A
LED1, LED4: LTST-C170KRKT; LEDC2012X120N; Manufacturer_Part_Number LTST-C170KRKT; Mouser Part Number 859-LTST-C170KRKT
LED2: LTST-C170TBKT; LEDC2012X120N; Manufacturer_Part_Number LTST-C170TBKT; Mouser Part Number 859-LTST-C170TBKT
LED3: LTST-C170GKT; LEDC2012X120N; Manufacturer_Part_Number LTST-C170GKT; Mouser Part Number 859-LTST-C170GKT
R1, R2: 10k; R_0805_2012Metric
R3, R4: 5k1; R_0805_2012Metric
R5: 2k; R_0805_2012Metric
R6: 20k; R_0805_2012Metric
R7, R8, R9, R10: 470; R_0805_2012Metric
U1: MCP73871; QFN-20-1EP_4x4mm_P0.5mm_EP2.5x2.5mm
VR1: LM1117MPX-3.3; VREG_LM1117MPX-3.3

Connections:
+3V3: C4.1, C5.1, LED4.2 (A), VR1.2 (VOUT_2), VR1.4 (VOUT_4); also elsewhere on the board
+5V: C2.1, C3.1, U1.1 (OUT), U1.20 (OUT), VR1.3 (VIN)
/+5V_USB: C6.1, F1.2, LED1.2 (A), LED2.2 (A), LED3.2 (A), U1.2 (VPCC), U1.4 (PROG2), U1.17 (CE), U1.18 (IN), U1.19 (IN)
/CHARGED: R8.1, U1.8 (STAT1/~LBO)
/CHARGING: R9.1, U1.6 (~PG)
/CHARGING_POWER: R7.1, U1.7 (STAT2)
/PWR_LED: LED4.1 (K), R10.2
/USB_DN: J1.A7 (DN1), J1.B7 (DN2); also elsewhere on the board
/USB_DP: J1.A6 (DP1), J1.B6 (DP2); also elsewhere on the board
/VBAT: J2.1, U1.14 (V_{BAT}), U1.15 (V_{BAT}), U1.16 (V_{BAT_SENSE})
/VBUS: C1.1, F1.1, J1.A4 (VBUSA1), J1.A9 (VBUSA2), J1.B4 (VBUSB1), J1.B9 (VBUSB2); also elsewhere on the board
unnamed: J1.A5 (CC1), R4.1
unnamed: J1.B5 (CC2), R3.1
unnamed: LED1.1 (K), R9.2
unnamed: LED2.1 (K), R7.2
unnamed: LED3.1 (K), R8.2
unnamed: R5.1, U1.13 (PROG1)
unnamed: R6.1, U1.12 (PROG3)
unnamed: R1.1, U1.9 (~TE)

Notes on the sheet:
Lipo battery charger
Low drop out (LDO) voltage regulator
Battery JST connector
USB Connector
Power indicator LED

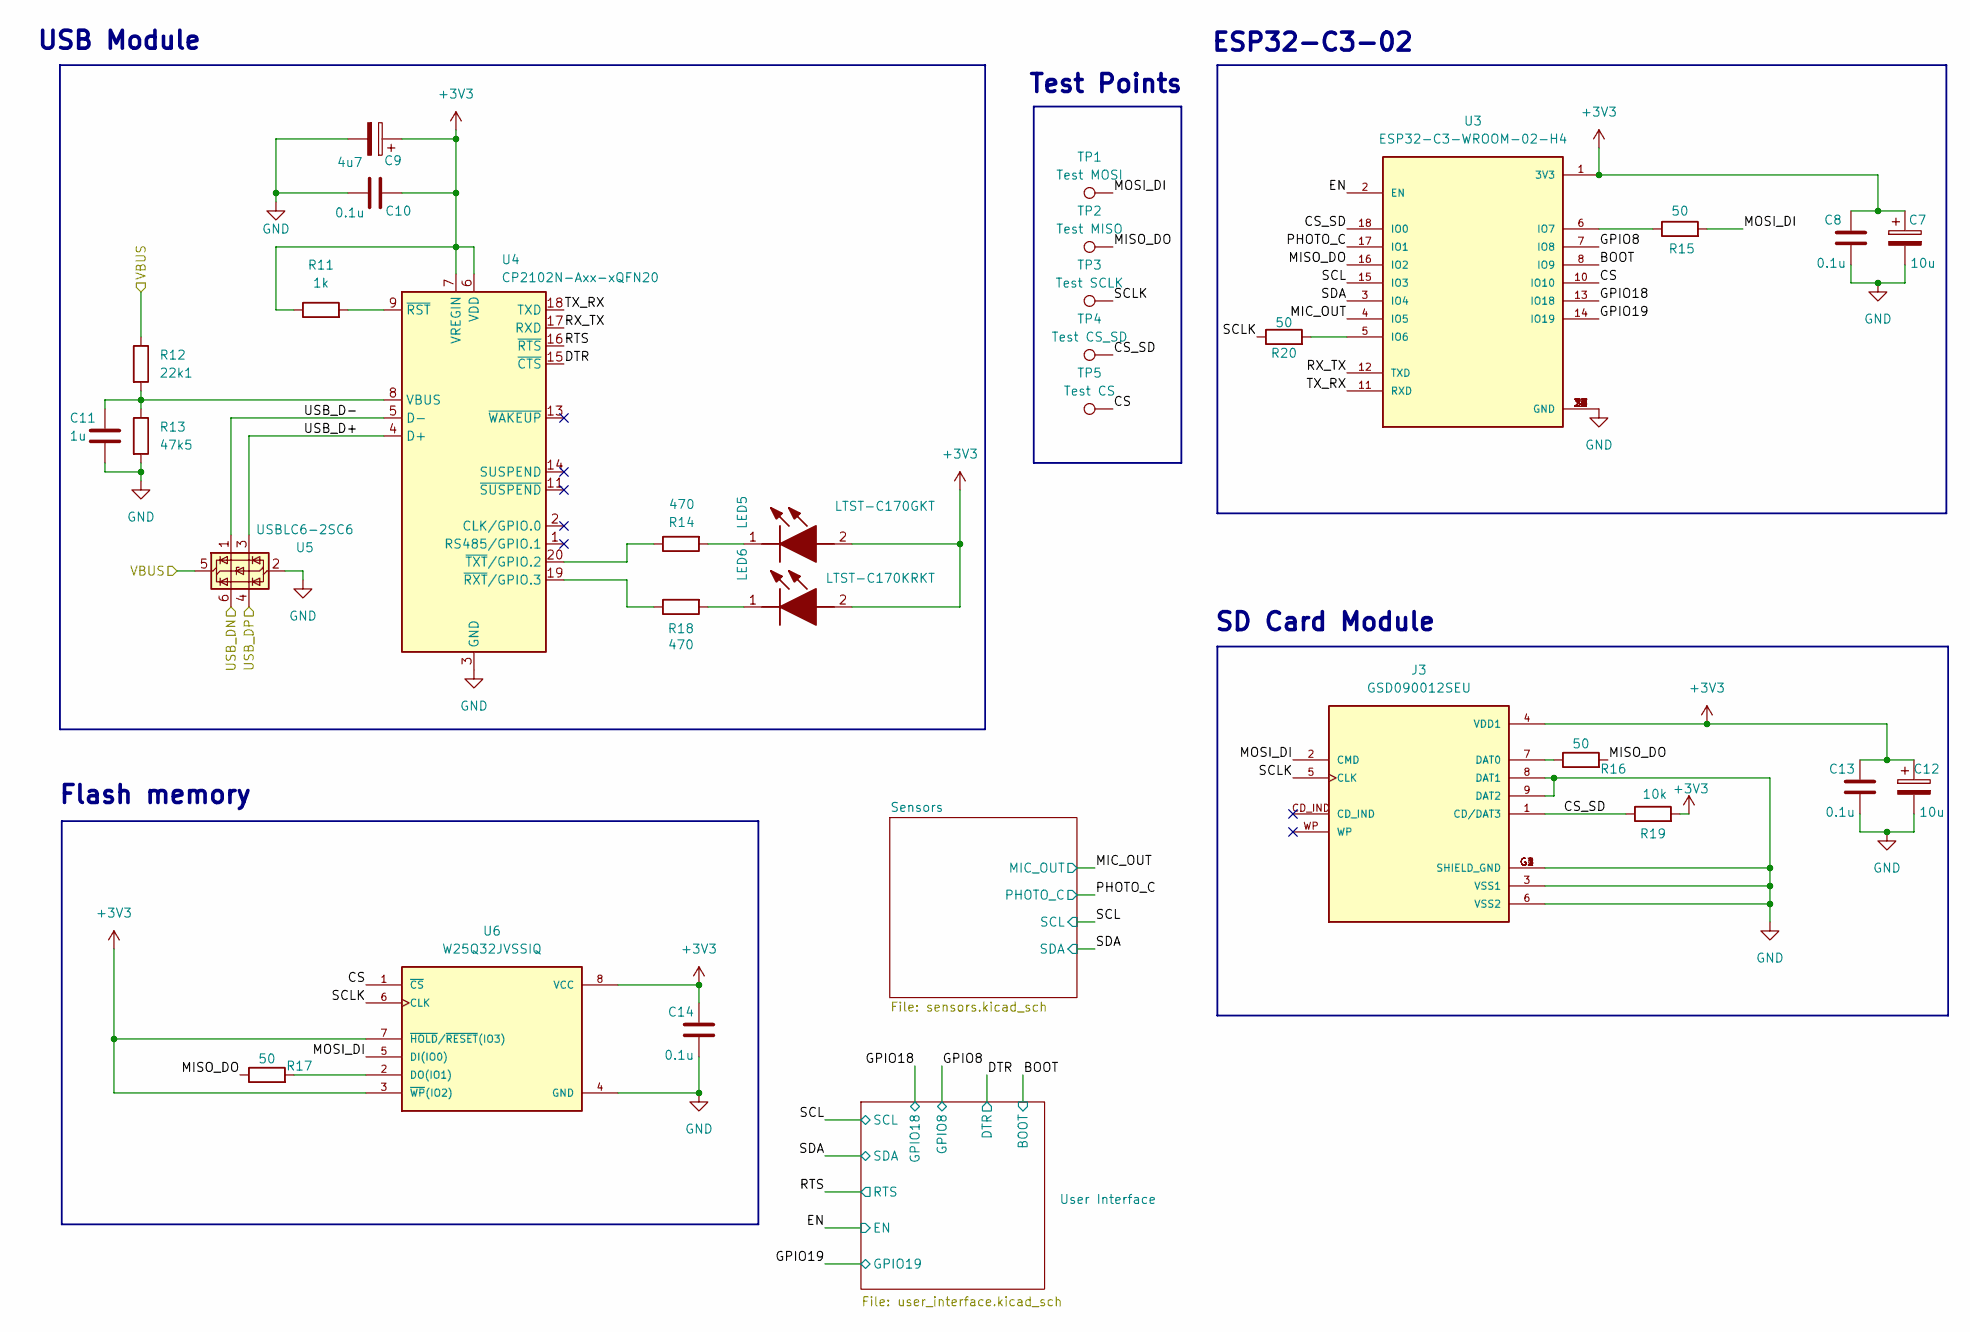
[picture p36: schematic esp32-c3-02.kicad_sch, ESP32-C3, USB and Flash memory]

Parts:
C7, C12: 10u; T491A
C8, C10, C13, C14: 0.1u; C_0805_2012Metric
C9: 4u7; T491A
C11: 1u; C_0805_2012Metric
J3: GSD090012SEU; AMPHENOL_GSD090012SEU; PARTREV E
LED5: LTST-C170GKT; LEDC2012X120N; Manufacturer_Part_Number LTST-C170GKT; Mouser Part Number 859-LTST-C170GKT
LED6: LTST-C170KRKT; LEDC2012X120N; Manufacturer_Part_Number LTST-C170KRKT; Mouser Part Number 859-LTST-C170KRKT
R11: 1k; R_0805_2012Metric
R12: 22k1; R_0805_2012Metric
R13: 47k5; R_0805_2012Metric
R14, R18: 470; R_0805_2012Metric
R15, R16, R17, R20: 50; R_0805_2012Metric
R19: 10k; R_0805_2012Metric
TP1: Test MOSI; TestPoint_Pad_D1.0mm
TP2: Test MISO; TestPoint_Pad_D1.0mm
TP3: Test SCLK; TestPoint_Pad_D1.0mm
TP4: Test CS_SD; TestPoint_Pad_D1.0mm
TP5: Test CS; TestPoint_Pad_D1.0mm
U3: ESP32-C3-WROOM-02-H4; MODULE_ESP32-C3-WROOM-02-H4
U4: CP2102N-Axx-xQFN20; SiliconLabs_QFN-20-1EP_3x3mm_P0.5mm_EP1.8x1.8mm
U5: USBLC6-2SC6; SOT-23-6
U6: W25Q32JVSSIQ; SOIC127P790X216-8N; M_PART_NUMBER W25QXX

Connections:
+3V3: C7.1, C8.2, C9.1, C10.2, C12.1, C13.2, C14.2, J3.4 (VDD1), LED5.2 (A), LED6.2 (A), R11.1, R19.2, U3.1 (3V3), U4.6 (VDD), U4.7 (VREGIN), U6.3 (~WP(IO2)), U6.7 (~HOLD/~RESET(IO3)), U6.8 (VCC); also elsewhere on the board
/ESP32-C3-02/BOOT: U3.8 (IO9); also elsewhere on the board
/ESP32-C3-02/CS: TP5.1, U3.10 (IO10), U6.1 (~CS)
/ESP32-C3-02/CS_SD: J3.1 (CD/DAT3), R19.1, TP4.1, U3.18 (IO0)
/ESP32-C3-02/DTR: U4.15 (~CTS); also elsewhere on the board
/ESP32-C3-02/EN: U3.2 (EN); also elsewhere on the board
/ESP32-C3-02/GPIO8: U3.7 (IO8); also elsewhere on the board
/ESP32-C3-02/GPIO18: U3.13 (IO18); also elsewhere on the board
/ESP32-C3-02/GPIO19: U3.14 (IO19); also elsewhere on the board
/ESP32-C3-02/MIC_OUT: U3.4 (IO5); also elsewhere on the board
/ESP32-C3-02/MISO_DO: R16.2, R17.1, TP2.1, U3.16 (IO2)
/ESP32-C3-02/MOSI_DI: J3.2 (CMD), R15.2, TP1.1, U6.5 (DI(IO0))
/ESP32-C3-02/PHOTO_C: U3.17 (IO1); also elsewhere on the board
/ESP32-C3-02/RTS: U4.16 (~RTS); also elsewhere on the board
/ESP32-C3-02/RX_TX: U3.12 (TXD), U4.17 (RXD)
/ESP32-C3-02/SCL: U3.15 (IO3); also elsewhere on the board
/ESP32-C3-02/SCLK: J3.5 (CLK), R20.1, TP3.1, U6.6 (CLK)
/ESP32-C3-02/SDA: U3.3 (IO4); also elsewhere on the board
/ESP32-C3-02/TX_RX: U3.11 (RXD), U4.18 (TXD)
/ESP32-C3-02/USB_D+: U4.4 (D+), U5.3 (I/O2)
/ESP32-C3-02/USB_D-: U4.5 (D-), U5.1 (I/O1)
/USB_DN: U5.6 (I/O1); also elsewhere on the board
/USB_DP: U5.4 (I/O2); also elsewhere on the board
/VBUS: R12.1, U5.5 (VBUS); also elsewhere on the board
unnamed: J3.7 (DAT0), R16.1
unnamed: LED5.1 (K), R14.2
unnamed: LED6.1 (K), R18.2
unnamed: R20.2, U3.5 (IO6)
unnamed: R15.1, U3.6 (IO7)
unnamed: C11.1, R12.2, R13.1, U4.8 (VBUS)
unnamed: R11.2, U4.9 (~RST)
unnamed: R18.1, U4.19 (~RXT/GPIO.3)
unnamed: R14.1, U4.20 (~TXT/GPIO.2)
unnamed: R17.2, U6.2 (DO(IO1))

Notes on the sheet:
USB Module
Test Points
SD Card Module
Flash memory
ESP32-C3-02

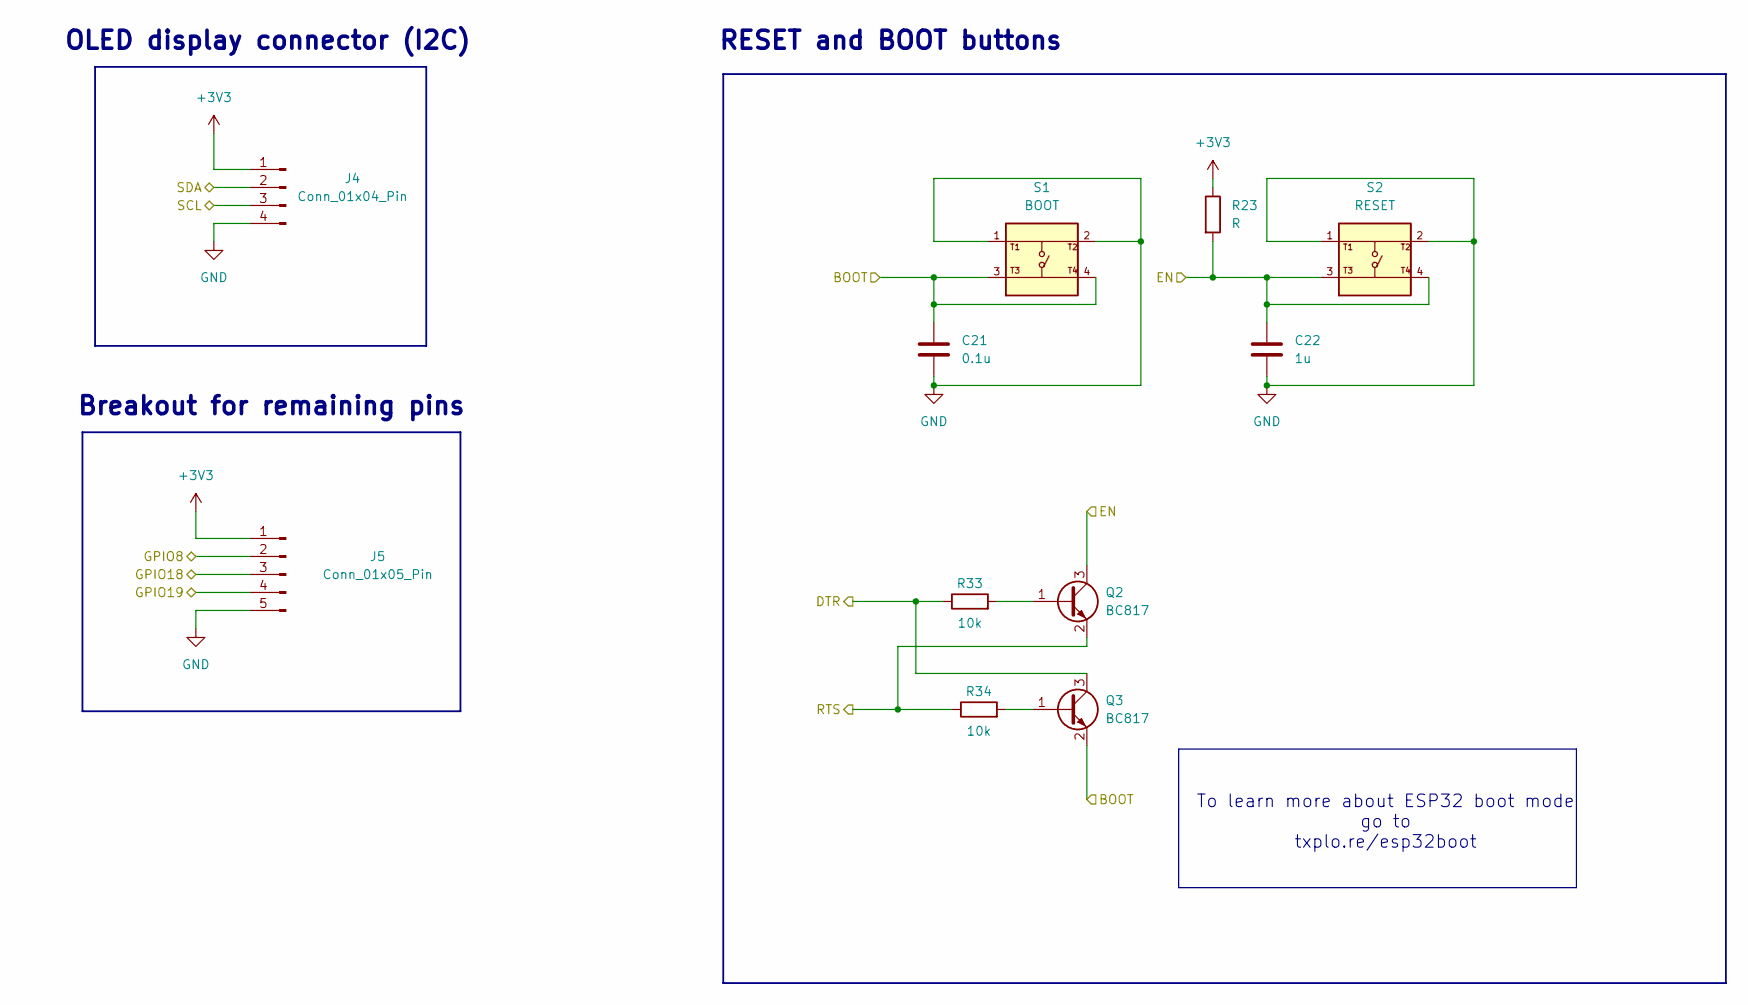
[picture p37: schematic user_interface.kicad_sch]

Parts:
C21: 0.1u; C_0805_2012Metric
C22: 1u; C_0805_2012Metric
J4: Conn_01x04_Pin; PinHeader_1x04_P2.54mm_Vertical
J5: Conn_01x05_Pin; PinHeader_1x05_P2.54mm_Vertical
Q2, Q3: BC817; SOT-23
R23: R; R_0805_2012Metric
R33, R34: 10k; R_0805_2012Metric
S1: BOOT; SW_USLPT2819DT2TR; PARTREV P
S2: RESET; SW_USLPT2819DT2TR; PARTREV P

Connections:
+3V3: J4.1, J5.1, R23.1; also elsewhere on the board
/ESP32-C3-02/BOOT: C21.1, Q3.2 (E), S1.3, S1.4; also elsewhere on the board
/ESP32-C3-02/DTR: Q3.3 (C), R33.1; also elsewhere on the board
/ESP32-C3-02/EN: C22.1, Q2.3 (C), R23.2, S2.3, S2.4; also elsewhere on the board
/ESP32-C3-02/GPIO8: J5.2; also elsewhere on the board
/ESP32-C3-02/GPIO18: J5.3; also elsewhere on the board
/ESP32-C3-02/GPIO19: J5.4; also elsewhere on the board
/ESP32-C3-02/RTS: Q2.2 (E), R34.1; also elsewhere on the board
/ESP32-C3-02/SCL: J4.3; also elsewhere on the board
/ESP32-C3-02/SDA: J4.2; also elsewhere on the board
unnamed: Q2.1 (B), R33.2
unnamed: Q3.1 (B), R34.2

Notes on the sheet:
Breakout for remaining pins
To learn more about ESP32 boot mode go to txplo.re/esp32boot
OLED display connector (I2C)
RESET and BOOT buttons

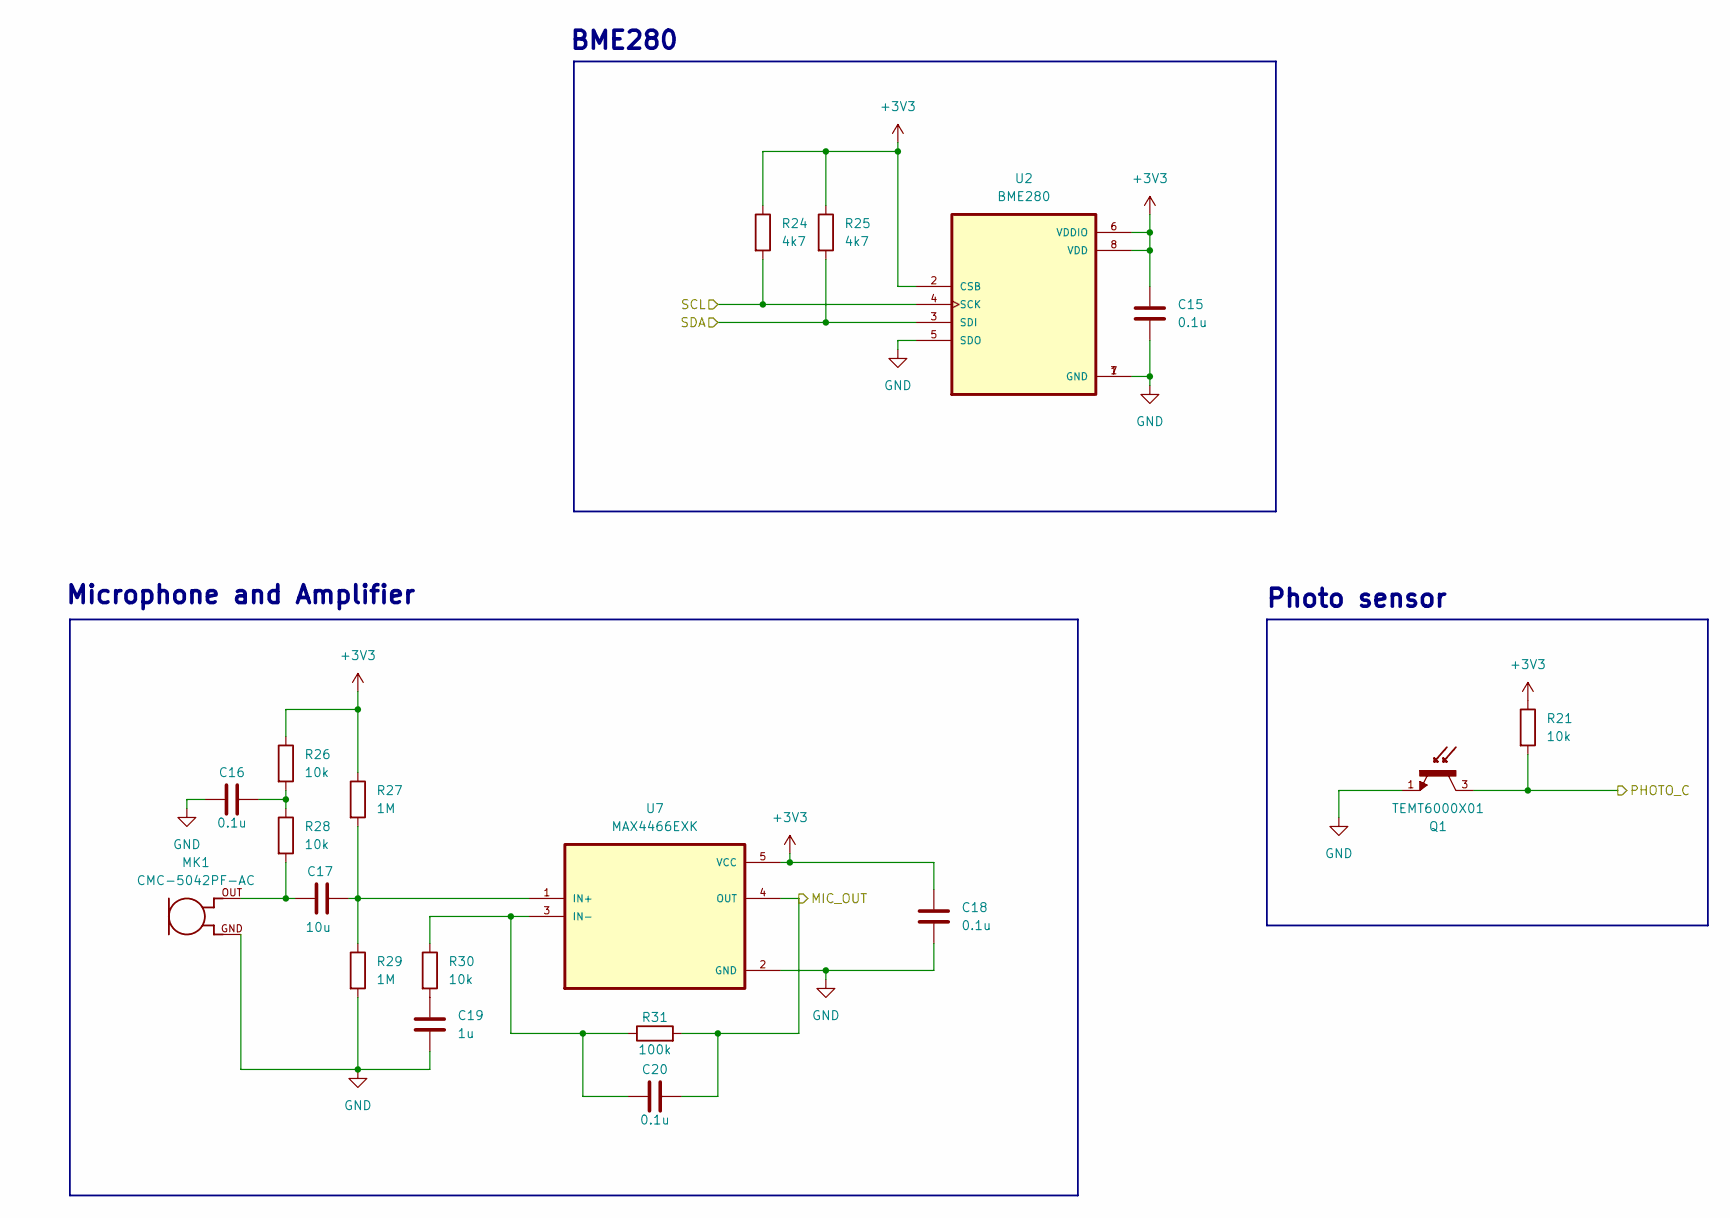
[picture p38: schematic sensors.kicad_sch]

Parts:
C15, C16, C18, C20: 0.1u; C_0805_2012Metric
C17: 10u; C_0805_2012Metric
C19: 1u; C_0805_2012Metric
MK1: CMC-5042PF-AC; CUI_CMC-5042PF-AC
Q1: TEMT6000X01; TRANS_TEMT6000X01; PARTREV 1.9
R21, R26, R28, R30: 10k; R_0805_2012Metric
R24, R25: 4k7; R_0805_2012Metric
R27, R29: 1M; R_0805_2012Metric
R31: 100k; R_0805_2012Metric
U2: BME280; PSON65P250X250X100-8N
U7: MAX4466EXK; SOT65P210X110-5N

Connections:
+3V3: C15.1, C18.1, R21.1, R24.1, R25.1, R26.1, R27.1, U2.2 (CSB), U2.6 (VDDIO), U2.8 (VDD), U7.5 (VCC); also elsewhere on the board
/ESP32-C3-02/MIC_OUT: C20.2, R31.2, U7.4 (OUT); also elsewhere on the board
/ESP32-C3-02/PHOTO_C: Q1.3, R21.2; also elsewhere on the board
/ESP32-C3-02/SCL: R24.2, U2.4 (SCK); also elsewhere on the board
/ESP32-C3-02/SDA: R25.2, U2.3 (SDI); also elsewhere on the board
unnamed: C16.2, R26.2, R28.1
unnamed: C17.1, MK1.OUT, R28.2
unnamed: C19.1, R30.2
unnamed: C17.2, R27.2, R29.1, U7.1 (IN+)
unnamed: C20.1, R30.1, R31.1, U7.3 (IN-)

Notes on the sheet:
Photo sensor
Microphone and Amplifier
BME280

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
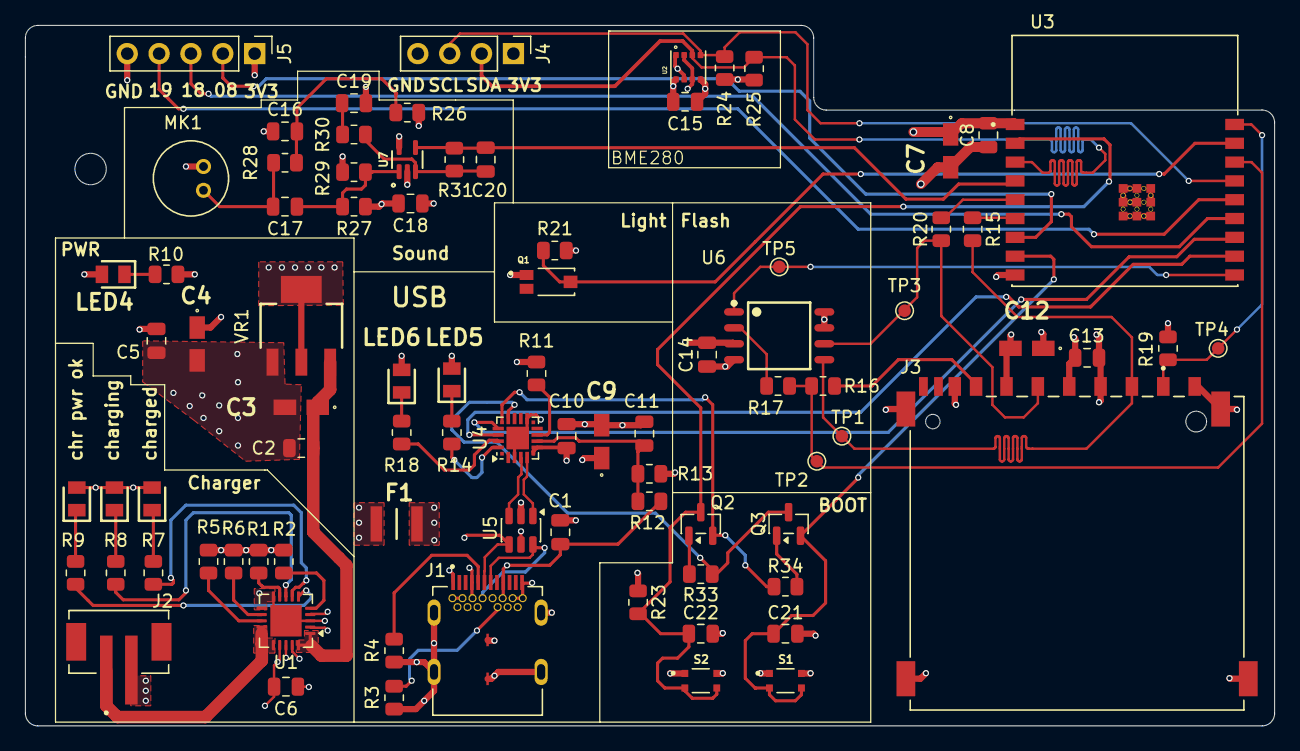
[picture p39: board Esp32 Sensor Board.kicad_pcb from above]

Board: 4 copper layers, 99.6 x 55.8 mm, 85 parts (0 on the bottom side), 58 nets.

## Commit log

2026-08-19 add source files
    [1-2295018-2.step, B2B-PH-SM4-TB.step, B4B-XH-AM__LF__SN_.step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]
2026-08-31 add PCB_Top
2026-09-11 add PCB_Bottom
2026-09-11 add manufacturing files
    [BOM.csv]
2026-09-13 Add README
    Added detailed project description, specifications, and gallery images for the ESP32 Sensor Board.
